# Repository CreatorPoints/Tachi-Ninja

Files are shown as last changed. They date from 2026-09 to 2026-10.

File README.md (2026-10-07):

# Tachi Ninja V2
A 60% Silent Linear mechanical keyboard that has per key RGB lighting and a display for pure asthetics! Made so that I can advance more in this fun cad pathway! [Now Hot-Swappable!]

---

## What was fun to make and what wasnt:
Well, it was overall a great project, I liked the most is the designing the pcb and making the case of this keyboard. But the ABSOLUTE brutal part was manually tracing all 424 pads :skull:

---

## Why did I make this?
I made it because I wanted a actually good keyboard, so instead of buying from online I decided to make my own. Advantages are I get to control how it would be and ofcource the flex :cool:

---

## Whats this "V2" Thingy?
So, when this project was submitted for forge, the reviewer returned the project for multiple reasons, one of it being incomplete PCBA, so, I improvised with something much better. The table would be the best:
|V1|V2|
|--|--|
|Permanent MX Switches|Kailh MX Hot Swappable sockets|
|Very crampy keycaps|Follows universal 19.05mm rule for keyboards|
|More compact, less polished|Kinda less compact, more polished|

## Need this? Here!
So, you need this same keyboard? NO PROBLEM! Its open-source!
1) Download this repo [assuming you know how to... just run git clone in your terminal]
2) Order the PCB - Preferebly from [JLCPCB](jlcpcb.com)
3) Gather the rest of the parts. Check [BOM](./BOM.md) 
4) Case files are in /CAD. Its upto you how to print [#Printing-Legion on slack].
5) Once your assembled PCB arrives, hand-solder the hot-swap sockets and OLED into the board (these are excluded from PCBA since they're through-hole/socketed). Press-fit switches into the hot-swap sockets and mount the PCB into the case and snap on keycaps.
6) Flash the firmware, hold both the BOOT and NRST button when turning on, it turns the stm32 to bootloader mode, drop the .h and json files on a STM32CubeProgrammer and Follow the steps there and then you are good to go!
7) Plug in via USB-C, confirm all 61 keys register, RGB lights up per-key, and the OLED display turns on! Yippe!

---

## Components used:
The following stuffs were used... Very hacky :)
- STM32F072C8Tx
- 1N4148 (x61)
- Kailh MX Hot Swappable Sockets (x61)
- SK6812MINI-E (x63)
- Resistors (x3)
- Capacitors (x6)
- Smol Switches (x2) - For boot & NRST purposes
- USB C 2.0 Receptable 16P
- AMS1117-3.3V
- 0.91 Inch I2C OLED Screen
- USBLC6-2SC6

---
## BOM

| Item | Link | Price | Shipping Cost |
| --- | --- | --- | --- |
| Switches (70x) | [HMX Taro Silent Linear](https://stackskb.com/store/hmx-taro-silent-linear-switch-pack-of-10/) | ₹2,625.00 / $27.39 | Free |
| Stabilizers | [Durock V2 Screw-in Stabilizers](https://stackskb.com/store/durock-clear-screw-in-stabilizers-v2/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) | ₹1,595.00 / $16.65 | Free |
| Keycaps | [dagaladoo Shine Through Keycaps](https://www.amazon.in/gp/product/B0DJH6L159/ref=ox_sc_act_title_1?smid=A2BWJVKSWP7TR2) | ₹2,500.00 / $26.12 | $5.00 |
| Hot Swap Sockets (70x) | [Gateron Sockets](https://stackskb.com/store/gateron-hotswap-sockets/) | ₹610.00 / $6.37 | Free |
| Solder Wire | [Lead-free Solder](https://www.amazon.in/SCHOFIC-Solder-Sn99-Ag0-3-Cu0-7-Weight-0-22lb/dp/B078C7SMKY/ref=sr_1_10?sr=8-10) | ₹385.00 / $4.02 | Free |
| PCB & Top Assembly (2 boards) | [JLCPCB](https://jlcpcb.com) | $53.21 | Included |
| Loose SMD Parts (LEDs, Diodes, CC Resistors) | [LCSC](https://www.lcsc.com) | $9.03 *(parts + handling)* | $42.03 |

Subtotal: $189.82  
Estimated Import Customs (20% – 45% on JLCPCB + LCSC):** ~$21.00 – $47.00 (~$36.50 mid)  
Total Estimated Request: ~$226.30

### For the full itemized breakdown, footprints, and part numbers, check:
[BOM.md](BOM.md)

---

## Images!
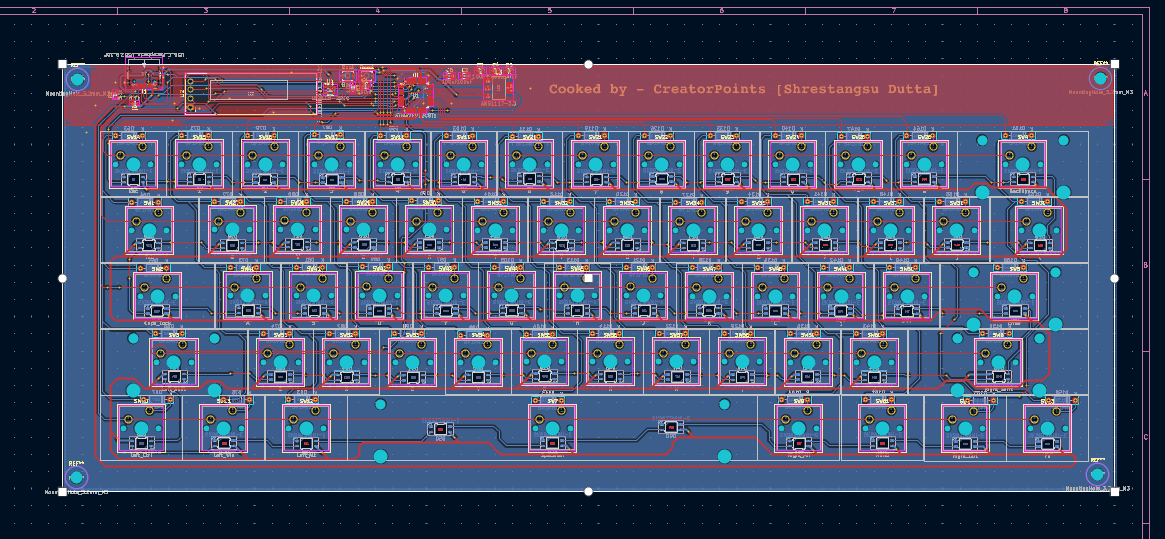
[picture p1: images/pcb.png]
A highly detailed PCB

### Wait, its V1
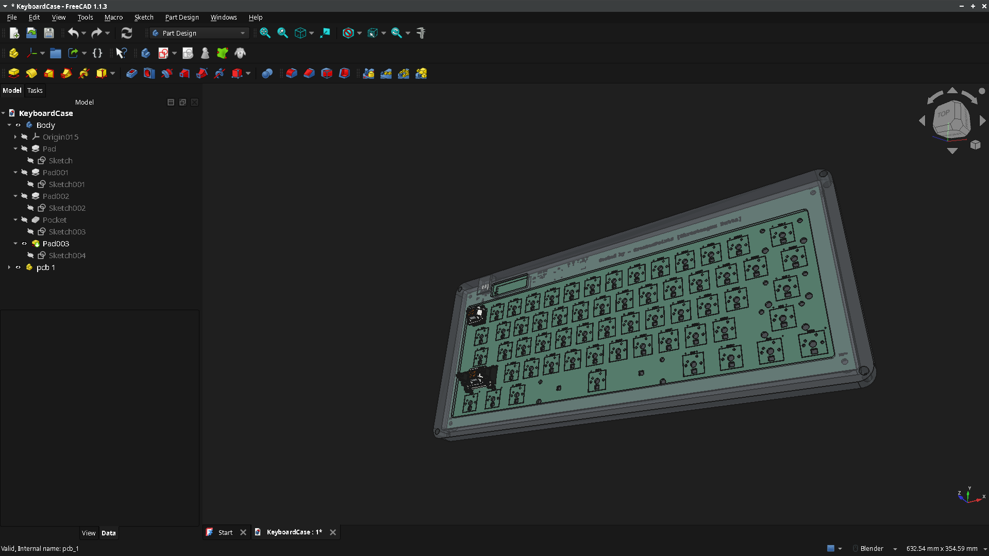
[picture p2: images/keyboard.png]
What a good case!

### From here V2 Development begins
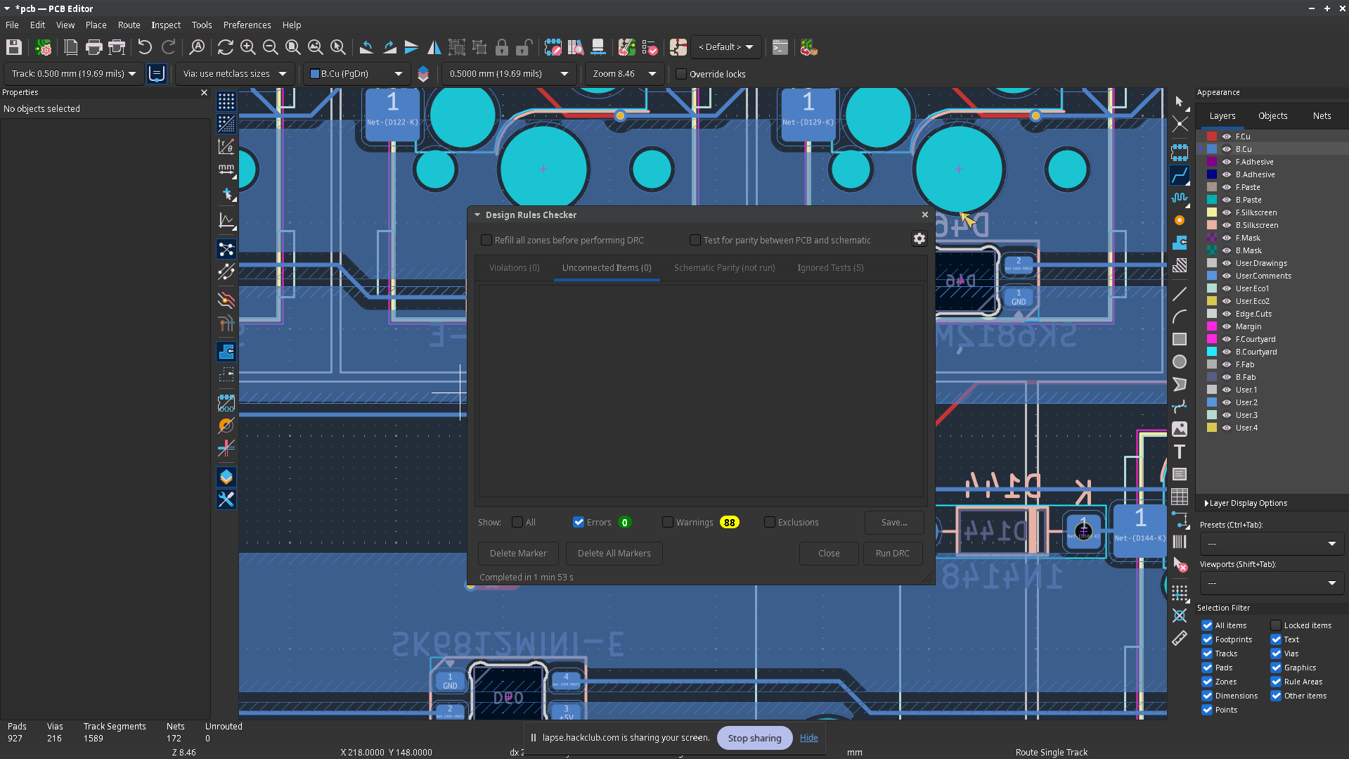
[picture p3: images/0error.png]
No Violations!

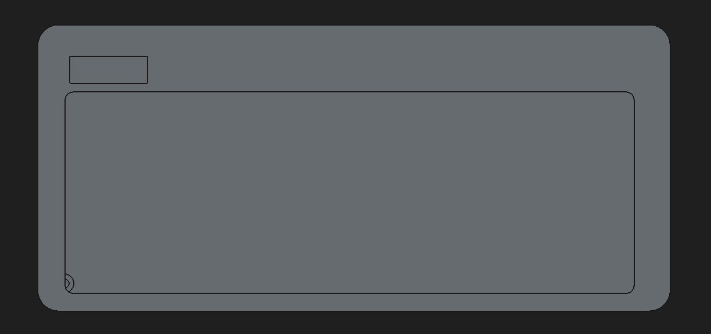
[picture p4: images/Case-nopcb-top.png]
a render

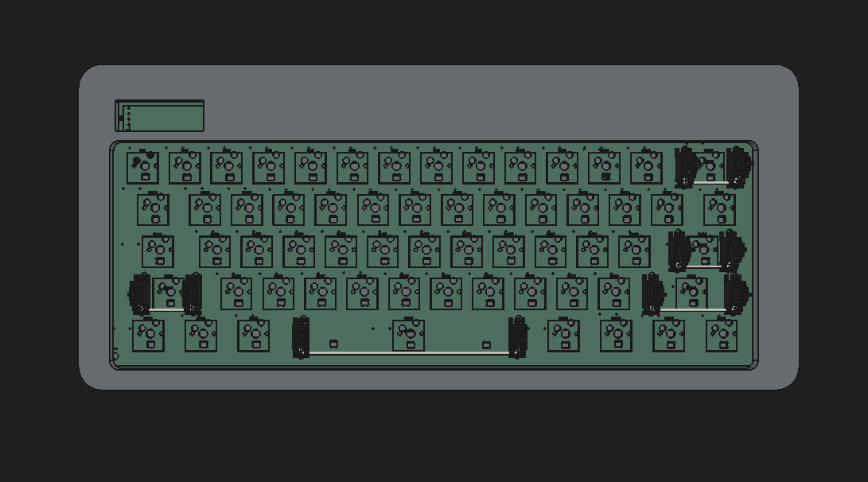
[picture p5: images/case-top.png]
another render

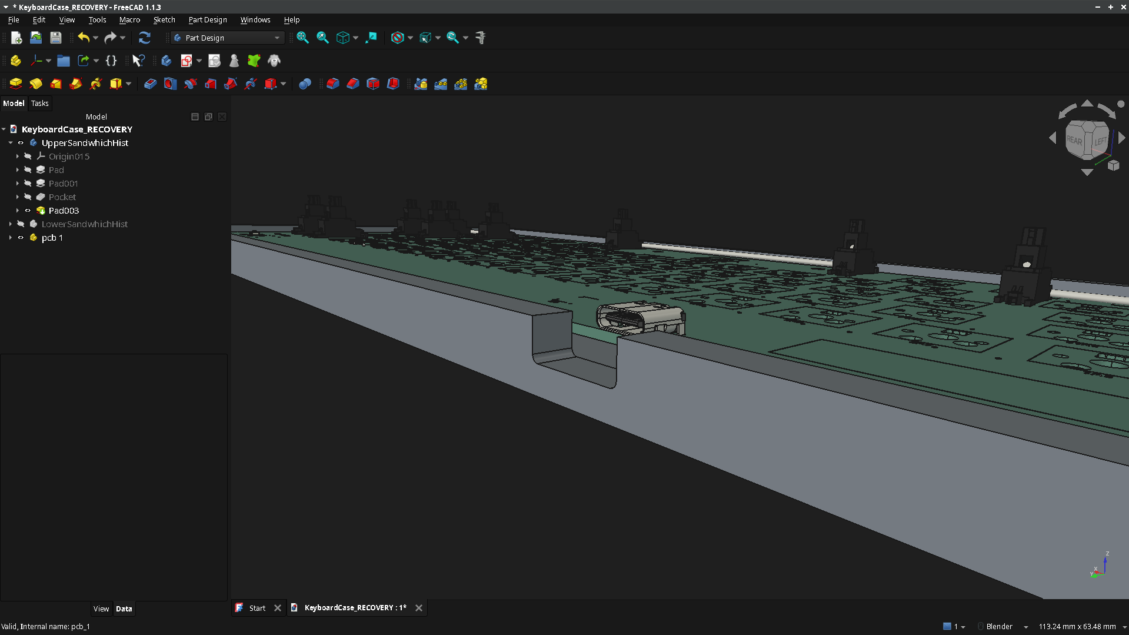
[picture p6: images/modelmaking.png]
i dont know

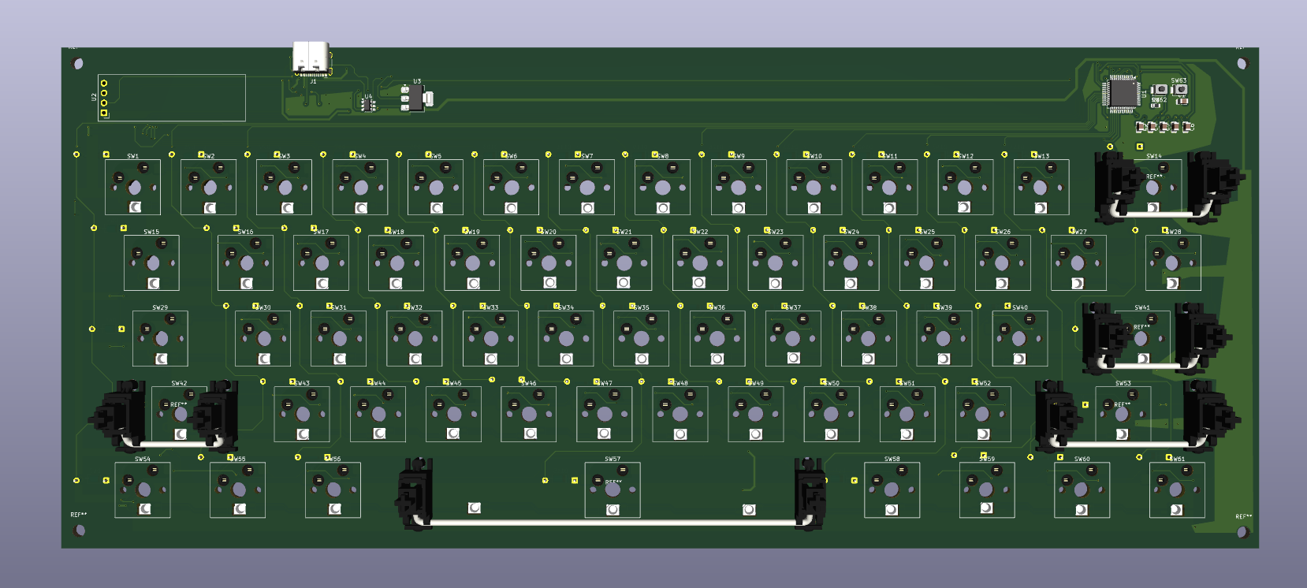
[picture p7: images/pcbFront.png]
pcb!


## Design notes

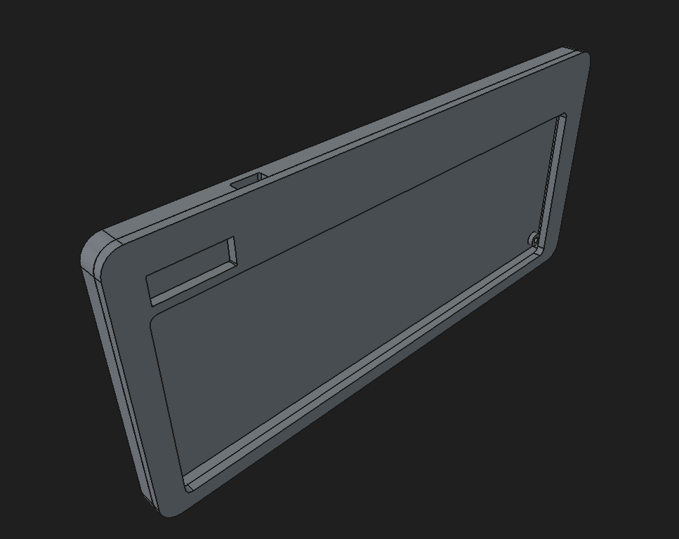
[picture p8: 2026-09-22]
images/case-nopcb-angled.png

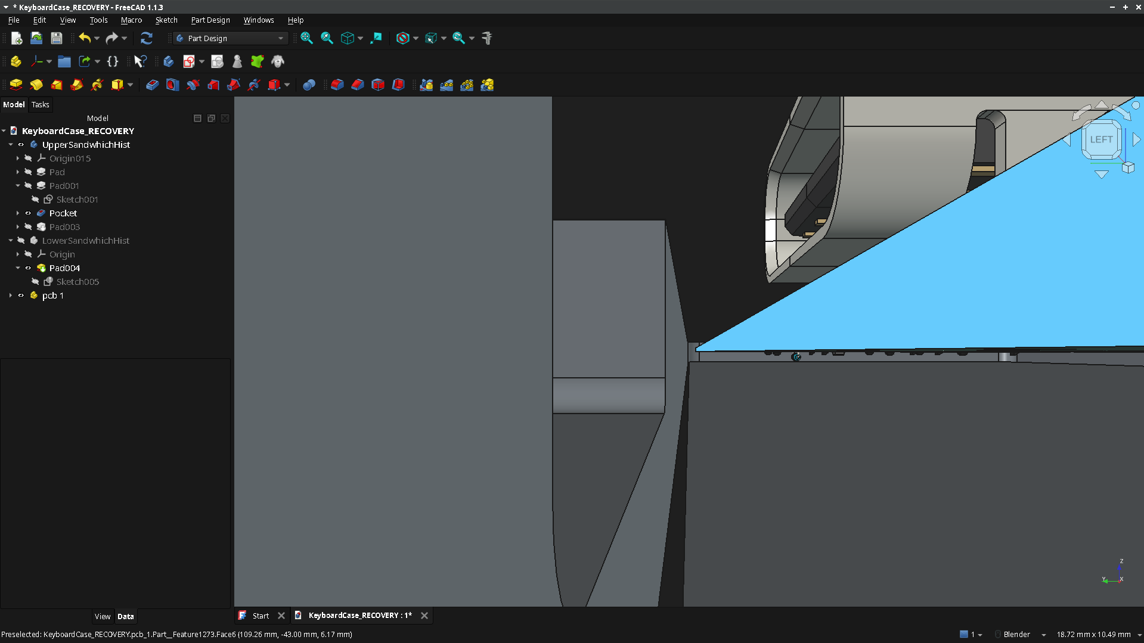
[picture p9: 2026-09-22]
images/checkmodel.png

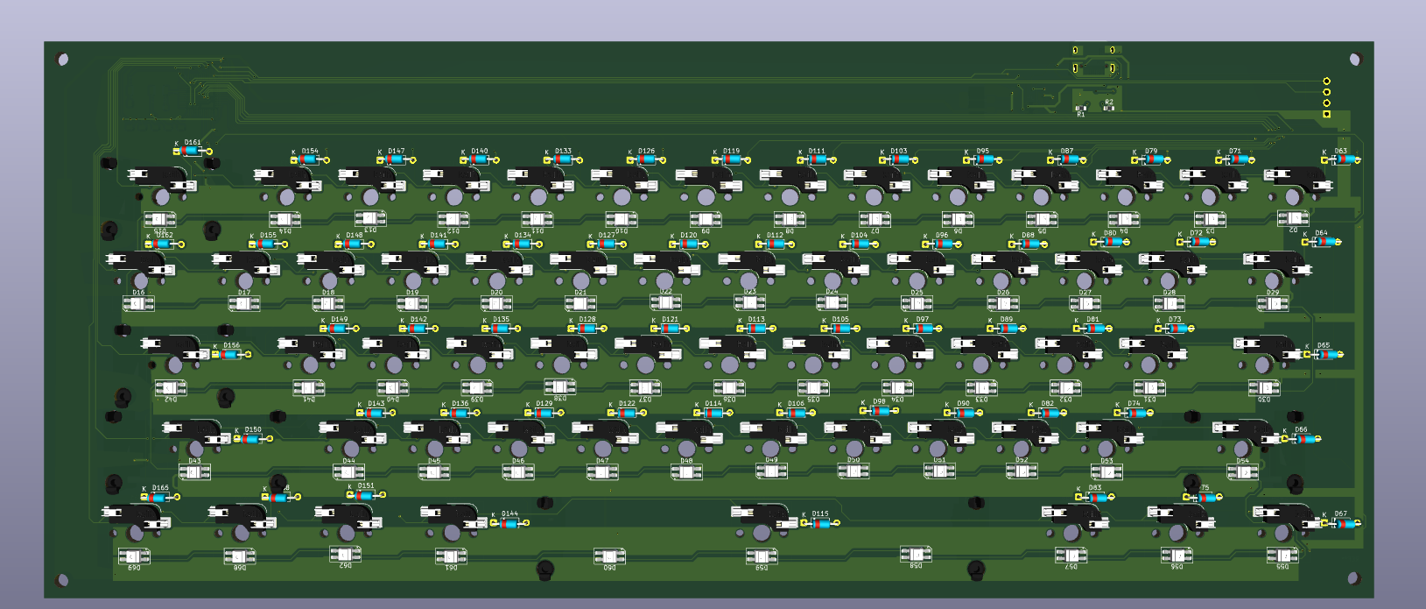
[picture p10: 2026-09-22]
images/pcbBack.png

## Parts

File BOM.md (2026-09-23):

# Bill of Materials
So, first thing is my JLCPCB cart screenshot, here:

### LCSC
| Index | LCSC# | MPN | Manufacturer | Package | Customer # | Description | RoHS | Quantity | MOQ | Multiple | Unit Price($) | Extended Price($) | Product Link |
| :---: | :---: | :---: | :---: | :---: | :---: | :--- | :---: | :---: | :---: | :---: | :---: | :---: | :--- |
| 1 | C5149201 | SK6812MINI-E | OPSCO Optoelectronics | SMD | | SMD LED Addressable, Specialty RoHS | yes | 75 | 5 | 5 | 0.065 | 4.88 | [Link](https://www.lcsc.com/product-detail/C5149201.html) |
| 2 | C402212 | 1N4148 | LGE | DO-35 | | Diode 75V 150mA Through Hole DO-35 | yes | 100 | 50 | 50 | 0.010 | 1.00 | [Link](https://www.lcsc.com/product-detail/C402212.html) |
| 3 | C23186 | 0603WAF5101T5E | UNI-ROYAL | 0603 | | 5.1kΩ ±1% 100mW 0603 Thick Film Resistor | yes | 100 | 100 | 100 | 0.0015 | 0.15 | [Link](https://www.lcsc.com/product-detail/C23186.html) |

YAY! JLCPCB after major removals now cost: $53.21!
and also LCSC: $45.25

Now comes the main costs:
|Sl. no.|Name|Item Link|Price|Shipping|Total|
|---|----|---|-----|---|-----|
|1|dagaladoo Shine Through keycaps Set|[Amazon](https://www.amazon.in/gp/product/B0DJH6L159/ref=ox_sc_act_title_1?smid=A2BWJVKSWP7TR2)|₹2,500 / $26.12|$5|$31.12|
|2|HMX Taro Silent Linear Switch|[StacksKB](https://stackskb.com/store/hmx-taro-silent-linear-switch-pack-of-10/)|₹2,625.00 / $27.39|Free|$27.39|
|3|Stabilizers|[StacksKB](https://stackskb.com/store/durock-clear-screw-in-stabilizers-v2/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)|₹1,595.00 / $16.65|Free|$16.65|
|4|Solder iron|[Amazon](https://www.amazon.in/SCHOFIC-Solder-Sn99-Ag0-3-Cu0-7-Weight-0-22lb/dp/B078C7SMKY/ref=sr_1_10?sr=8-10)|₹385 / $4.02|Free|$10 [as more are needed for more components and i dont own one yet]|
|5|Hot Swap Sockets|[StacksKB](https://stackskb.com/store/gateron-hotswap-sockets/)|₹610 / $6.37|Free|$6.37|

### Final Budget Summary

* **Base Build Total:** **$195.80** (~₹18,740)
* **Customs Buffer Range:** **$20.85 – $46.92** (~₹1,995 – ₹4,490)
* **Final Full Price (with Expected Duties):** **$216.65 – $242.72**  
  *(Recommended Grant Request with mid-range buffer: **$232.29** / ~₹22,230)*

[Used ai for only summary cuz i didnt knew much about customs]

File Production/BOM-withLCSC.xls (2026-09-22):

JLCPCB BOM Tool - BOM Matching
BOM name：bom-JLCPCB Assembly Order.xlsx |  |  | Download Time：2026-09-23 04:56:11 |  |  |  | * Our matching results are updated in real-time, but stock and prices may change. If it's been over 24 hours, please re-match before placing your order.
PCB Assembled Qty：5 |  |  | Est. Total Price：298.9473
Your BOM |  |  |  | Matched Parts |  |  |  |  |  |  | Order Information
Designator | Comment | Footprint | JLCPCB Part # | Matches | Part # | Manufacturer | Footprint | Description | Category | Warning | JLCPCB Part # | Product link | Lib Type | Qty | Source | Total Price ($)
C1,C2,C3,C4,C5,C6 | 100nF | 0805 |  | Select by System | CC0805KRX7R9BB104 | YAGEO | 0805 | 100nF 50V X7R ±10% 0805 Multilayer Ceramic Capacitors MLCC - SMD/SMT ROHS | Multilayer Ceramic Capacitors MLCC - SMD/SMT |  | C49678 | https://jlcpcb.com/partdetail/YAGEO-CC0805KRX7R9BB104/C49678 | Basic | 22 | 22 JLCPCB | 0.4246
D10,D11,D12,D13,D14,D15,D16,D17,D18,D19,D2,D20,D21,D22,D23,D24,D25,D26,D27,D28,D29,D3,D30,D31,D32,D33,D34,D35,D36,D37,D38,D39,D4,D40,D41,D42,D43,D44,D45,D46,D47,D48,D49,D5,D50,D51,D52,D53,D54,D55,D56,D57,D58,D59,D6,D60,D61,D62,D68,D69,D7,D8,D9 | SK6812MINI-E | LED_SK6812MINI-E_3.2x2.8mm_P1.5mm_ReverseMount |  | Select by System | SK6812MINI-E | OPSCO Optoelectronics | SMD | -40℃~+85℃ 0.6mA 1.78mm 120mcd~240mcd 120° 160mcd~320mcd 1kHz 2.8mm 2000V 3.2mm 3.7V~5.5V 460nm~470nm 515nm~525nm 620nm~625nm 800Kbit/s 815mcd~1275mcd Semi-transparent lens SMD RGB LEDs(Built-in IC) ROHS | RGB LEDs(Built-In IC) |  | C5149201 | https://jlcpcb.com/partdetail/OPSCOOptoelectronics-SK6812MINIE/C5149201 | Extended | 128 | 128 JLCPCB | 8.256
D103,D104,D105,D106,D111,D112,D113,D114,D115,D119,D120,D121,D122,D126,D127,D128,D129,D133,D134,D135,D136,D140,D141,D142,D143,D144,D147,D148,D149,D150,D151,D154,D155,D156,D158,D161,D162,D165,D63,D64,D65,D66,D67,D71,D72,D73,D74,D75,D79,D80,D81,D82,D83,D87,D88,D89,D90,D95,D96,D97,D98 | 1N4148 | D_DO-35_SOD27_P7.62mm_Horizontal |  | Select by System | 1N4148 | LGE | DO-35 | 1 Independent 150mA 1V@10mA 2A 4ns 500mW 5uA@75V 75V DO-35 Switching Diodes ROHS | Switching Diodes |  | C402212 | https://jlcpcb.com/partdetail/LGE-1N4148/C402212 | Extended | 127 | 127 JLCPCB | 1.2573
J1 | USB_C_Receptacle_USB2.0_16P | USB_C_Receptacle_HCTL_HC-TYPE-C-16P-01A |  | Select by Customer | USB4105-GF-A | Global Connector Technology | SMD | -40℃~+85℃ 1 12P 48V 5A Black Female Surface Mount, Right Angle Type-C USB 2.0 SMD USB Connectors ROHS | USB Connectors |  | C3020560 | https://jlcpcb.com/partdetail/3542626-USB4105_GFA/C3020560 | Extended | 2 | 2 JLCPCB | 2.5984
R1,R2 | 5.1k | 0603 |  | Unconfirmed | 0603WAF5101T5E | UNI-ROYAL(Uniroyal Elec) | 0603 | -55℃~+155℃ 100mW 5.1kΩ 75V Thick Film Resistor ±1% ±100ppm/℃ 0603 Chip Resistor - Surface Mount ROHS | Chip Resistor - Surface Mount | 1.The comment (0603WAF5101T5E) of this part does not match the one (5.1k) provided in your BOM. Please confirm; | C23186 | https://jlcpcb.com/partdetail/23913-0603WAF5101T5E/C23186 | Basic | 20 | 20 JLCPCB | 0.036
R3 | 10k | 0603 |  | Unconfirmed | 0603WAF1002T5E | UNI-ROYAL(Uniroyal Elec) | 0603 | -55℃~+155℃ 100mW 10kΩ 75V Thick Film Resistor ±1% ±100ppm/℃ 0603 Chip Resistor - Surface Mount ROHS | Chip Resistor - Surface Mount | 1.The comment (0603WAF1002T5E) of this part does not match the one (10k) provided in your BOM. Please confirm; | C25804 | https://jlcpcb.com/partdetail/26547-0603WAF1002T5E/C25804 | Basic | 20 | 20 JLCPCB | 0.036
SW1 | ESC | SW_Hotswap_Kailh_MX_1.00u |  | Select by Customer | CPG151101S11-16 | HanElectricity | SMD,14.5x5.9mm | 12V 2 3000gf 5,000 cycles SMD,14.5x5.9mm Mechanical Keyboard Shaft ROHS | Mechanical Keyboard Shaft | 1.Multiple lines in the BOM have been matched to the same part. Please check if the matching is correct. ; | C41430893 | https://jlcpcb.com/partdetail/HanElectricity-CPG151101S1116/C41430893 | Extended | 122 | 122 JLCPCB | 4.4774
SW2 | 1 | SW_Hotswap_Kailh_MX_1.00u |  | Select by Customer | CPG151101S11-16 | HanElectricity | SMD,14.5x5.9mm | 12V 2 3000gf 5,000 cycles SMD,14.5x5.9mm Mechanical Keyboard Shaft ROHS | Mechanical Keyboard Shaft | 1.The comment (CPG151101S11-16) of this part does not match the one (1) provided in your BOM. Please confirm; 2.Multiple lines in the BOM have been matched to the same part. Please check if the matching is correct. ; | C41430893 | https://jlcpcb.com/partdetail/HanElectricity-CPG151101S1116/C41430893 | Extended | 122 | 122 JLCPCB | 4.4774
SW3 | 2 | SW_Hotswap_Kailh_MX_1.00u |  | Select by Customer | CPG151101S11-16 | HanElectricity | SMD,14.5x5.9mm | 12V 2 3000gf 5,000 cycles SMD,14.5x5.9mm Mechanical Keyboard Shaft ROHS | Mechanical Keyboard Shaft | 1.Multiple lines in the BOM have been matched to the same part. Please check if the matching is correct. ; | C41430893 | https://jlcpcb.com/partdetail/HanElectricity-CPG151101S1116/C41430893 | Extended | 122 | 122 JLCPCB | 4.4774
SW4 | 3 | SW_Hotswap_Kailh_MX_1.00u |  | Select by Customer | CPG151101S11-16 | HanElectricity | SMD,14.5x5.9mm | 12V 2 3000gf 5,000 cycles SMD,14.5x5.9mm Mechanical Keyboard Shaft ROHS | Mechanical Keyboard Shaft | 1.The comment (CPG151101S11-16) of this part does not match the one (3) provided in your BOM. Please confirm; 2.Multiple lines in the BOM have been matched to the same part. Please check if the matching is correct. ; | C41430893 | https://jlcpcb.com/partdetail/HanElectricity-CPG151101S1116/C41430893 | Extended | 122 | 122 JLCPCB | 4.4774
SW5 | 4 | SW_Hotswap_Kailh_MX_1.00u |  | Select by Customer | CPG151101S11-16 | HanElectricity | SMD,14.5x5.9mm | 12V 2 3000gf 5,000 cycles SMD,14.5x5.9mm Mechanical Keyboard Shaft ROHS | Mechanical Keyboard Shaft | 1.The comment (CPG151101S11-16) of this part does not match the one (4) provided in your BOM. Please confirm; 2.Multiple lines in the BOM have been matched to the same part. Please check if the matching is correct. ; | C41430893 | https://jlcpcb.com/partdetail/HanElectricity-CPG151101S1116/C41430893 | Extended | 122 | 122 JLCPCB | 4.4774
SW6 | 5 | SW_Hotswap_Kailh_MX_1.00u |  | Select by Customer | CPG151101S11-16 | HanElectricity | SMD,14.5x5.9mm | 12V 2 3000gf 5,000 cycles SMD,14.5x5.9mm Mechanical Keyboard Shaft ROHS | Mechanical Keyboard Shaft | 1.The comment (CPG151101S11-16) of this part does not match the one (5) provided in your BOM. Please confirm; 2.Multiple lines in the BOM have been matched to the same part. Please check if the matching is correct. ; | C41430893 | https://jlcpcb.com/partdetail/HanElectricity-CPG151101S1116/C41430893 | Extended | 122 | 122 JLCPCB | 4.4774
SW7 | 6 | SW_Hotswap_Kailh_MX_1.00u |  | Select by Customer | CPG151101S11-16 | HanElectricity | SMD,14.5x5.9mm | 12V 2 3000gf 5,000 cycles SMD,14.5x5.9mm Mechanical Keyboard Shaft ROHS | Mechanical Keyboard Shaft | 1.The comment (CPG151101S11-16) of this part does not match the one (6) provided in your BOM. Please confirm; 2.Multiple lines in the BOM have been matched to the same part. Please check if the matching is correct. ; | C41430893 | https://jlcpcb.com/partdetail/HanElectricity-CPG151101S1116/C41430893 | Extended | 122 | 122 JLCPCB | 4.4774
SW8 | 7 | SW_Hotswap_Kailh_MX_1.00u |  | Select by Customer | CPG151101S11-16 | HanElectricity | SMD,14.5x5.9mm | 12V 2 3000gf 5,000 cycles SMD,14.5x5.9mm Mechanical Keyboard Shaft ROHS | Mechanical Keyboard Shaft | 1.The comment (CPG151101S11-16) of this part does not match the one (7) provided in your BOM. Please confirm; 2.Multiple lines in the BOM have been matched to the same part. Please check if the matching is correct. ; | C41430893 | https://jlcpcb.com/partdetail/HanElectricity-CPG151101S1116/C41430893 | Extended | 122 | 122 JLCPCB | 4.4774
SW9 | 8 | SW_Hotswap_Kailh_MX_1.00u |  | Select by Customer | CPG151101S11-16 | HanElectricity | SMD,14.5x5.9mm | 12V 2 3000gf 5,000 cycles SMD,14.5x5.9mm Mechanical Keyboard Shaft ROHS | Mechanical Keyboard Shaft | 1.The comment (CPG151101S11-16) of this part does not match the one (8) provided in your BOM. Please confirm; 2.Multiple lines in the BOM have been matched to the same part. Please check if the matching is correct. ; | C41430893 | https://jlcpcb.com/partdetail/HanElectricity-CPG151101S1116/C41430893 | Extended | 122 | 122 JLCPCB | 4.4774
SW10 | 9 | SW_Hotswap_Kailh_MX_1.00u |  | Select by Customer | CPG151101S11-16 | HanElectricity | SMD,14.5x5.9mm | 12V 2 3000gf 5,000 cycles SMD,14.5x5.9mm Mechanical Keyboard Shaft ROHS | Mechanical Keyboard Shaft | 1.The comment (CPG151101S11-16) of this part does not match the one (9) provided in your BOM. Please confirm; 2.Multiple lines in the BOM have been matched to the same part. Please check if the matching is correct. ; | C41430893 | https://jlcpcb.com/partdetail/HanElectricity-CPG151101S1116/C41430893 | Extended | 122 | 122 JLCPCB | 4.4774
SW11 | 0 | SW_Hotswap_Kailh_MX_1.00u |  | Select by Customer | CPG151101S11-16 | HanElectricity | SMD,14.5x5.9mm | 12V 2 3000gf 5,000 cycles SMD,14.5x5.9mm Mechanical Keyboard Shaft ROHS | Mechanical Keyboard Shaft | 1.The comment (CPG151101S11-16) of this part does not match the one (0) provided in your BOM. Please confirm; 2.Multiple lines in the BOM have been matched to the same part. Please check if the matching is correct. ; | C41430893 | https://jlcpcb.com/partdetail/HanElectricity-CPG151101S1116/C41430893 | Extended | 122 | 122 JLCPCB | 4.4774
SW12 | - | SW_Hotswap_Kailh_MX_1.00u |  | Select by Customer | CPG151101S11-16 | HanElectricity | SMD,14.5x5.9mm | 12V 2 3000gf 5,000 cycles SMD,14.5x5.9mm Mechanical Keyboard Shaft ROHS | Mechanical Keyboard Shaft | 1.Multiple lines in the BOM have been matched to the same part. Please check if the matching is correct. ; | C41430893 | https://jlcpcb.com/partdetail/HanElectricity-CPG151101S1116/C41430893 | Extended | 122 | 122 JLCPCB | 4.4774
SW13 | = | SW_Hotswap_Kailh_MX_1.00u |  | Select by Customer | CPG151101S11-16 | HanElectricity | SMD,14.5x5.9mm | 12V 2 3000gf 5,000 cycles SMD,14.5x5.9mm Mechanical Keyboard Shaft ROHS | Mechanical Keyboard Shaft | 1.Multiple lines in the BOM have been matched to the same part. Please check if the matching is correct. ; | C41430893 | https://jlcpcb.com/partdetail/HanElectricity-CPG151101S1116/C41430893 | Extended | 122 | 122 JLCPCB | 4.4774
SW14 | BACKSPACE | SW_Hotswap_Kailh_MX_2.00u |  | Select by Customer | CPG151101S11-16 | HanElectricity | SMD,14.5x5.9mm | 12V 2 3000gf 5,000 cycles SMD,14.5x5.9mm Mechanical Keyboard Shaft ROHS | Mechanical Keyboard Shaft | 1.Multiple lines in the BOM have been matched to the same part. Please check if the matching is correct. ; | C41430893 | https://jlcpcb.com/partdetail/HanElectricity-CPG151101S1116/C41430893 | Extended | 122 | 122 JLCPCB | 4.4774
SW15 | TAB | SW_Hotswap_Kailh_MX_1.50u |  | Select by Customer | CPG151101S11-16 | HanElectricity | SMD,14.5x5.9mm | 12V 2 3000gf 5,000 cycles SMD,14.5x5.9mm Mechanical Keyboard Shaft ROHS | Mechanical Keyboard Shaft | 1.Multiple lines in the BOM have been matched to the same part. Please check if the matching is correct. ; | C41430893 | https://jlcpcb.com/partdetail/HanElectricity-CPG151101S1116/C41430893 | Extended | 122 | 122 JLCPCB | 4.4774
SW16 | Q | SW_Hotswap_Kailh_MX_1.00u |  | Select by Customer | CPG151101S11-16 | HanElectricity | SMD,14.5x5.9mm | 12V 2 3000gf 5,000 cycles SMD,14.5x5.9mm Mechanical Keyboard Shaft ROHS | Mechanical Keyboard Shaft | 1.Multiple lines in the BOM have been matched to the same part. Please check if the matching is correct. ; | C41430893 | https://jlcpcb.com/partdetail/HanElectricity-CPG151101S1116/C41430893 | Extended | 122 | 122 JLCPCB | 4.4774
SW17 | W | SW_Hotswap_Kailh_MX_1.00u |  | Unconfirmed | CPG151101S11-16 | HanElectricity | SMD,14.5x5.9mm | 12V 2 3000gf 5,000 cycles SMD,14.5x5.9mm Mechanical Keyboard Shaft ROHS | Mechanical Keyboard Shaft | 1.Multiple lines in the BOM have been matched to the same part. Please check if the matching is correct. ; | C41430893 | https://jlcpcb.com/partdetail/HanElectricity-CPG151101S1116/C41430893 | Extended | 122 | 122 JLCPCB | 4.4774
SW18 | E | SW_Hotswap_Kailh_MX_1.00u |  | Select by Customer | CPG151101S11-16 | HanElectricity | SMD,14.5x5.9mm | 12V 2 3000gf 5,000 cycles SMD,14.5x5.9mm Mechanical Keyboard Shaft ROHS | Mechanical Keyboard Shaft | 1.Multiple lines in the BOM have been matched to the same part. Please check if the matching is correct. ; | C41430893 | https://jlcpcb.com/partdetail/HanElectricity-CPG151101S1116/C41430893 | Extended | 122 | 122 JLCPCB | 4.4774
SW19 | R | SW_Hotswap_Kailh_MX_1.00u |  | Select by Customer | CPG151101S11-16 | HanElectricity | SMD,14.5x5.9mm | 12V 2 3000gf 5,000 cycles SMD,14.5x5.9mm Mechanical Keyboard Shaft ROHS | Mechanical Keyboard Shaft | 1.Multiple lines in the BOM have been matched to the same part. Please check if the matching is correct. ; | C41430893 | https://jlcpcb.com/partdetail/HanElectricity-CPG151101S1116/C41430893 | Extended | 122 | 122 JLCPCB | 4.4774
SW20 | T | SW_Hotswap_Kailh_MX_1.00u |  | Select by Customer | CPG151101S11-16 | HanElectricity | SMD,14.5x5.9mm | 12V 2 3000gf 5,000 cycles SMD,14.5x5.9mm Mechanical Keyboard Shaft ROHS | Mechanical Keyboard Shaft | 1.Multiple lines in the BOM have been matched to the same part. Please check if the matching is correct. ; | C41430893 | https://jlcpcb.com/partdetail/HanElectricity-CPG151101S1116/C41430893 | Extended | 122 | 122 JLCPCB | 4.4774
SW21 | Y | SW_Hotswap_Kailh_MX_1.00u |  | Select by Customer | CPG151101S11-16 | HanElectricity | SMD,14.5x5.9mm | 12V 2 3000gf 5,000 cycles SMD,14.5x5.9mm Mechanical Keyboard Shaft ROHS | Mechanical Keyboard Shaft | 1.Multiple lines in the BOM have been matched to the same part. Please check if the matching is correct. ; | C41430893 | https://jlcpcb.com/partdetail/HanElectricity-CPG151101S1116/C41430893 | Extended | 122 | 122 JLCPCB | 4.4774
SW22 | U | SW_Hotswap_Kailh_MX_1.00u |  | Select by Customer | CPG151101S11-16 | HanElectricity | SMD,14.5x5.9mm | 12V 2 3000gf 5,000 cycles SMD,14.5x5.9mm Mechanical Keyboard Shaft ROHS | Mechanical Keyboard Shaft | 1.Multiple lines in the BOM have been matched to the same part. Please check if the matching is correct. ; | C41430893 | https://jlcpcb.com/partdetail/HanElectricity-CPG151101S1116/C41430893 | Extended | 122 | 122 JLCPCB | 4.4774
SW23 | I | SW_Hotswap_Kailh_MX_1.00u |  | Select by Customer | CPG151101S11-16 | HanElectricity | SMD,14.5x5.9mm | 12V 2 3000gf 5,000 cycles SMD,14.5x5.9mm Mechanical Keyboard Shaft ROHS | Mechanical Keyboard Shaft | 1.Multiple lines in the BOM have been matched to the same part. Please check if the matching is correct. ; | C41430893 | https://jlcpcb.com/partdetail/HanElectricity-CPG151101S1116/C41430893 | Extended | 122 | 122 JLCPCB | 4.4774
SW24 | O | SW_Hotswap_Kailh_MX_1.00u |  | Select by Customer | CPG151101S11-16 | HanElectricity | SMD,14.5x5.9mm | 12V 2 3000gf 5,000 cycles SMD,14.5x5.9mm Mechanical Keyboard Shaft ROHS | Mechanical Keyboard Shaft | 1.Multiple lines in the BOM have been matched to the same part. Please check if the matching is correct. ; | C41430893 | https://jlcpcb.com/partdetail/HanElectricity-CPG151101S1116/C41430893 | Extended | 122 | 122 JLCPCB | 4.4774
SW25 | P | SW_Hotswap_Kailh_MX_1.00u |  | Select by Customer | CPG151101S11-16 | HanElectricity | SMD,14.5x5.9mm | 12V 2 3000gf 5,000 cycles SMD,14.5x5.9mm Mechanical Keyboard Shaft ROHS | Mechanical Keyboard Shaft | 1.Multiple lines in the BOM have been matched to the same part. Please check if the matching is correct. ; | C41430893 | https://jlcpcb.com/partdetail/HanElectricity-CPG151101S1116/C41430893 | Extended | 122 | 122 JLCPCB | 4.4774
SW26 | [ | SW_Hotswap_Kailh_MX_1.00u |  | Select by Customer | CPG151101S11-16 | HanElectricity | SMD,14.5x5.9mm | 12V 2 3000gf 5,000 cycles SMD,14.5x5.9mm Mechanical Keyboard Shaft ROHS | Mechanical Keyboard Shaft | 1.Multiple lines in the BOM have been matched to the same part. Please check if the matching is correct. ; | C41430893 | https://jlcpcb.com/partdetail/HanElectricity-CPG151101S1116/C41430893 | Extended | 122 | 122 JLCPCB | 4.4774
SW27 | ] | SW_Hotswap_Kailh_MX_1.00u |  | Select by Customer | CPG151101S11-16 | HanElectricity | SMD,14.5x5.9mm | 12V 2 3000gf 5,000 cycles SMD,14.5x5.9mm Mechanical Keyboard Shaft ROHS | Mechanical Keyboard Shaft | 1.Multiple lines in the BOM have been matched to the same part. Please check if the matching is correct. ; | C41430893 | https://jlcpcb.com/partdetail/HanElectricity-CPG151101S1116/C41430893 | Extended | 122 | 122 JLCPCB | 4.4774
SW28 | \ | SW_Hotswap_Kailh_MX_1.50u |  | Select by Customer | CPG151101S11-16 | HanElectricity | SMD,14.5x5.9mm | 12V 2 3000gf 5,000 cycles SMD,14.5x5.9mm Mechanical Keyboard Shaft ROHS | Mechanical Keyboard Shaft | 1.Multiple lines in the BOM have been matched to the same part. Please check if the matching is correct. ; | C41430893 | https://jlcpcb.com/partdetail/HanElectricity-CPG151101S1116/C41430893 | Extended | 122 | 122 JLCPCB | 4.4774
SW29 | CAPSLOCK | SW_Hotswap_Kailh_MX_1.75u |  | Select by Customer | CPG151101S11-16 | HanElectricity | SMD,14.5x5.9mm | 12V 2 3000gf 5,000 cycles SMD,14.5x5.9mm Mechanical Keyboard Shaft ROHS | Mechanical Keyboard Shaft | 1.Multiple lines in the BOM have been matched to the same part. Please check if the matching is correct. ; | C41430893 | https://jlcpcb.com/partdetail/HanElectricity-CPG151101S1116/C41430893 | Extended | 122 | 122 JLCPCB | 4.4774
SW30 | A | SW_Hotswap_Kailh_MX_1.00u |  | Select by Customer | CPG151101S11-16 | HanElectricity | SMD,14.5x5.9mm | 12V 2 3000gf 5,000 cycles SMD,14.5x5.9mm Mechanical Keyboard Shaft ROHS | Mechanical Keyboard Shaft | 1.Multiple lines in the BOM have been matched to the same part. Please check if the matching is correct. ; | C41430893 | https://jlcpcb.com/partdetail/HanElectricity-CPG151101S1116/C41430893 | Extended | 122 | 122 JLCPCB | 4.4774
SW31 | S | SW_Hotswap_Kailh_MX_1.00u |  | Select by Customer | CPG151101S11-16 | HanElectricity | SMD,14.5x5.9mm | 12V 2 3000gf 5,000 cycles SMD,14.5x5.9mm Mechanical Keyboard Shaft ROHS | Mechanical Keyboard Shaft | 1.Multiple lines in the BOM have been matched to the same part. Please check if the matching is correct. ; | C41430893 | https://jlcpcb.com/partdetail/HanElectricity-CPG151101S1116/C41430893 | Extended | 122 | 122 JLCPCB | 4.4774
SW32 | D | SW_Hotswap_Kailh_MX_1.00u |  | Select by Customer | CPG151101S11-16 | HanElectricity | SMD,14.5x5.9mm | 12V 2 3000gf 5,000 cycles SMD,14.5x5.9mm Mechanical Keyboard Shaft ROHS | Mechanical Keyboard Shaft | 1.Multiple lines in the BOM have been matched to the same part. Please check if the matching is correct. ; | C41430893 | https://jlcpcb.com/partdetail/HanElectricity-CPG151101S1116/C41430893 | Extended | 122 | 122 JLCPCB | 4.4774
SW33 | F | SW_Hotswap_Kailh_MX_1.00u |  | Select by Customer | CPG151101S11-16 | HanElectricity | SMD,14.5x5.9mm | 12V 2 3000gf 5,000 cycles SMD,14.5x5.9mm Mechanical Keyboard Shaft ROHS | Mechanical Keyboard Shaft | 1.Multiple lines in the BOM have been matched to the same part. Please check if the matching is correct. ; | C41430893 | https://jlcpcb.com/partdetail/HanElectricity-CPG151101S1116/C41430893 | Extended | 122 | 122 JLCPCB | 4.4774
SW34 | G | SW_Hotswap_Kailh_MX_1.00u |  | Select by Customer | CPG151101S11-16 | HanElectricity | SMD,14.5x5.9mm | 12V 2 3000gf 5,000 cycles SMD,14.5x5.9mm Mechanical Keyboard Shaft ROHS | Mechanical Keyboard Shaft | 1.Multiple lines in the BOM have been matched to the same part. Please check if the matching is correct. ; | C41430893 | https://jlcpcb.com/partdetail/HanElectricity-CPG151101S1116/C41430893 | Extended | 122 | 122 JLCPCB | 4.4774
SW35 | H | SW_Hotswap_Kailh_MX_1.00u |  | Select by Customer | CPG151101S11-16 | HanElectricity | SMD,14.5x5.9mm | 12V 2 3000gf 5,000 cycles SMD,14.5x5.9mm Mechanical Keyboard Shaft ROHS | Mechanical Keyboard Shaft | 1.Multiple lines in the BOM have been matched to the same part. Please check if the matching is correct. ; | C41430893 | https://jlcpcb.com/partdetail/HanElectricity-CPG151101S1116/C41430893 | Extended | 122 | 122 JLCPCB | 4.4774
SW36 | J | SW_Hotswap_Kailh_MX_1.00u |  | Select by Customer | CPG151101S11-16 | HanElectricity | SMD,14.5x5.9mm | 12V 2 3000gf 5,000 cycles SMD,14.5x5.9mm Mechanical Keyboard Shaft ROHS | Mechanical Keyboard Shaft | 1.Multiple lines in the BOM have been matched to the same part. Please check if the matching is correct. ; | C41430893 | https://jlcpcb.com/partdetail/HanElectricity-CPG151101S1116/C41430893 | Extended | 122 | 122 JLCPCB | 4.4774
SW37 | K | SW_Hotswap_Kailh_MX_1.00u |  | Select by Customer | CPG151101S11-16 | HanElectricity | SMD,14.5x5.9mm | 12V 2 3000gf 5,000 cycles SMD,14.5x5.9mm Mechanical Keyboard Shaft ROHS | Mechanical Keyboard Shaft | 1.Multiple lines in the BOM have been matched to the same part. Please check if the matching is correct. ; | C41430893 | https://jlcpcb.com/partdetail/HanElectricity-CPG151101S1116/C41430893 | Extended | 122 | 122 JLCPCB | 4.4774
SW38 | L | SW_Hotswap_Kailh_MX_1.00u |  | Select by Customer | CPG151101S11-16 | HanElectricity | SMD,14.5x5.9mm | 12V 2 3000gf 5,000 cycles SMD,14.5x5.9mm Mechanical Keyboard Shaft ROHS | Mechanical Keyboard Shaft | 1.Multiple lines in the BOM have been matched to the same part. Please check if the matching is correct. ; | C41430893 | https://jlcpcb.com/partdetail/HanElectricity-CPG151101S1116/C41430893 | Extended | 122 | 122 JLCPCB | 4.4774
SW39 | ; | SW_Hotswap_Kailh_MX_1.00u |  | Select by Customer | CPG151101S11-16 | HanElectricity | SMD,14.5x5.9mm | 12V 2 3000gf 5,000 cycles SMD,14.5x5.9mm Mechanical Keyboard Shaft ROHS | Mechanical Keyboard Shaft | 1.Multiple lines in the BOM have been matched to the same part. Please check if the matching is correct. ; | C41430893 | https://jlcpcb.com/partdetail/HanElectricity-CPG151101S1116/C41430893 | Extended | 122 | 122 JLCPCB | 4.4774
SW40 | ' | SW_Hotswap_Kailh_MX_1.00u |  | Select by Customer | CPG151101S11-16 | HanElectricity | SMD,14.5x5.9mm | 12V 2 3000gf 5,000 cycles SMD,14.5x5.9mm Mechanical Keyboard Shaft ROHS | Mechanical Keyboard Shaft | 1.Multiple lines in the BOM have been matched to the same part. Please check if the matching is correct. ; | C41430893 | https://jlcpcb.com/partdetail/HanElectricity-CPG151101S1116/C41430893 | Extended | 122 | 122 JLCPCB | 4.4774
SW41 | ENTER | SW_Hotswap_Kailh_MX_2.25u |  | Select by Customer | CPG151101S11-16 | HanElectricity | SMD,14.5x5.9mm | 12V 2 3000gf 5,000 cycles SMD,14.5x5.9mm Mechanical Keyboard Shaft ROHS | Mechanical Keyboard Shaft | 1.Multiple lines in the BOM have been matched to the same part. Please check if the matching is correct. ; | C41430893 | https://jlcpcb.com/partdetail/HanElectricity-CPG151101S1116/C41430893 | Extended | 122 | 122 JLCPCB | 4.4774
SW42 | LEFTSHIFT | SW_Hotswap_Kailh_MX_2.25u |  | Select by Customer | CPG151101S11-16 | HanElectricity | SMD,14.5x5.9mm | 12V 2 3000gf 5,000 cycles SMD,14.5x5.9mm Mechanical Keyboard Shaft ROHS | Mechanical Keyboard Shaft | 1.Multiple lines in the BOM have been matched to the same part. Please check if the matching is correct. ; | C41430893 | https://jlcpcb.com/partdetail/HanElectricity-CPG151101S1116/C41430893 | Extended | 122 | 122 JLCPCB | 4.4774
SW43 | Z | SW_Hotswap_Kailh_MX_1.00u |  | Select by Customer | CPG151101S11-16 | HanElectricity | SMD,14.5x5.9mm | 12V 2 3000gf 5,000 cycles SMD,14.5x5.9mm Mechanical Keyboard Shaft ROHS | Mechanical Keyboard Shaft | 1.Multiple lines in the BOM have been matched to the same part. Please check if the matching is correct. ; | C41430893 | https://jlcpcb.com/partdetail/HanElectricity-CPG151101S1116/C41430893 | Extended | 122 | 122 JLCPCB | 4.4774
SW44 | X | SW_Hotswap_Kailh_MX_1.00u |  | Select by Customer | CPG151101S11-16 | HanElectricity | SMD,14.5x5.9mm | 12V 2 3000gf 5,000 cycles SMD,14.5x5.9mm Mechanical Keyboard Shaft ROHS | Mechanical Keyboard Shaft | 1.Multiple lines in the BOM have been matched to the same part. Please check if the matching is correct. ; | C41430893 | https://jlcpcb.com/partdetail/HanElectricity-CPG151101S1116/C41430893 | Extended | 122 | 122 JLCPCB | 4.4774
SW45 | C | SW_Hotswap_Kailh_MX_1.00u |  | Select by Customer | CPG151101S11-16 | HanElectricity | SMD,14.5x5.9mm | 12V 2 3000gf 5,000 cycles SMD,14.5x5.9mm Mechanical Keyboard Shaft ROHS | Mechanical Keyboard Shaft | 1.Multiple lines in the BOM have been matched to the same part. Please check if the matching is correct. ; | C41430893 | https://jlcpcb.com/partdetail/HanElectricity-CPG151101S1116/C41430893 | Extended | 122 | 122 JLCPCB | 4.4774
SW46 | V | SW_Hotswap_Kailh_MX_1.00u |  | Select by Customer | CPG151101S11-16 | HanElectricity | SMD,14.5x5.9mm | 12V 2 3000gf 5,000 cycles SMD,14.5x5.9mm Mechanical Keyboard Shaft ROHS | Mechanical Keyboard Shaft | 1.Multiple lines in the BOM have been matched to the same part. Please check if the matching is correct. ; | C41430893 | https://jlcpcb.com/partdetail/HanElectricity-CPG151101S1116/C41430893 | Extended | 122 | 122 JLCPCB | 4.4774
SW47 | B | SW_Hotswap_Kailh_MX_1.00u |  | Select by Customer | CPG151101S11-16 | HanElectricity | SMD,14.5x5.9mm | 12V 2 3000gf 5,000 cycles SMD,14.5x5.9mm Mechanical Keyboard Shaft ROHS | Mechanical Keyboard Shaft | 1.Multiple lines in the BOM have been matched to the same part. Please check if the matching is correct. ; | C41430893 | https://jlcpcb.com/partdetail/HanElectricity-CPG151101S1116/C41430893 | Extended | 122 | 122 JLCPCB | 4.4774
SW48 | N | SW_Hotswap_Kailh_MX_1.00u |  | Select by Customer | CPG151101S11-16 | HanElectricity | SMD,14.5x5.9mm | 12V 2 3000gf 5,000 cycles SMD,14.5x5.9mm Mechanical Keyboard Shaft ROHS | Mechanical Keyboard Shaft | 1.Multiple lines in the BOM have been matched to the same part. Please check if the matching is correct. ; | C41430893 | https://jlcpcb.com/partdetail/HanElectricity-CPG151101S1116/C41430893 | Extended | 122 | 122 JLCPCB | 4.4774
SW49 | M | SW_Hotswap_Kailh_MX_1.00u |  | Select by Customer | CPG151101S11-16 | HanElectricity | SMD,14.5x5.9mm | 12V 2 3000gf 5,000 cycles SMD,14.5x5.9mm Mechanical Keyboard Shaft ROHS | Mechanical Keyboard Shaft | 1.Multiple lines in the BOM have been matched to the same part. Please check if the matching is correct. ; | C41430893 | https://jlcpcb.com/partdetail/HanElectricity-CPG151101S1116/C41430893 | Extended | 122 | 122 JLCPCB | 4.4774
SW50 | , | SW_Hotswap_Kailh_MX_1.00u |  | Select by Customer | CPG151101S11-16 | HanElectricity | SMD,14.5x5.9mm | 12V 2 3000gf 5,000 cycles SMD,14.5x5.9mm Mechanical Keyboard Shaft ROHS | Mechanical Keyboard Shaft | 1.Multiple lines in the BOM have been matched to the same part. Please check if the matching is correct. ; | C41430893 | https://jlcpcb.com/partdetail/HanElectricity-CPG151101S1116/C41430893 | Extended | 122 | 122 JLCPCB | 4.4774
SW51 | . | SW_Hotswap_Kailh_MX_1.00u |  | Select by Customer | CPG151101S11-16 | HanElectricity | SMD,14.5x5.9mm | 12V 2 3000gf 5,000 cycles SMD,14.5x5.9mm Mechanical Keyboard Shaft ROHS | Mechanical Keyboard Shaft | 1.Multiple lines in the BOM have been matched to the same part. Please check if the matching is correct. ; | C41430893 | https://jlcpcb.com/partdetail/HanElectricity-CPG151101S1116/C41430893 | Extended | 122 | 122 JLCPCB | 4.4774
SW52 | / | SW_Hotswap_Kailh_MX_1.00u |  | Select by Customer | CPG151101S11-16 | HanElectricity | SMD,14.5x5.9mm | 12V 2 3000gf 5,000 cycles SMD,14.5x5.9mm Mechanical Keyboard Shaft ROHS | Mechanical Keyboard Shaft | 1.Multiple lines in the BOM have been matched to the same part. Please check if the matching is correct. ; | C41430893 | https://jlcpcb.com/partdetail/HanElectricity-CPG151101S1116/C41430893 | Extended | 122 | 122 JLCPCB | 4.4774
SW53 | RIGHTSHIFT | SW_Hotswap_Kailh_MX_2.75u |  | Select by Customer | CPG151101S11-16 | HanElectricity | SMD,14.5x5.9mm | 12V 2 3000gf 5,000 cycles SMD,14.5x5.9mm Mechanical Keyboard Shaft ROHS | Mechanical Keyboard Shaft | 1.Multiple lines in the BOM have been matched to the same part. Please check if the matching is correct. ; | C41430893 | https://jlcpcb.com/partdetail/HanElectricity-CPG151101S1116/C41430893 | Extended | 122 | 122 JLCPCB | 4.4774
SW54 | LEFTCTRL | SW_Hotswap_Kailh_MX_1.25u |  | Select by Customer | CPG151101S11-16 | HanElectricity | SMD,14.5x5.9mm | 12V 2 3000gf 5,000 cycles SMD,14.5x5.9mm Mechanical Keyboard Shaft ROHS | Mechanical Keyboard Shaft | 1.Multiple lines in the BOM have been matched to the same part. Please check if the matching is correct. ; | C41430893 | https://jlcpcb.com/partdetail/HanElectricity-CPG151101S1116/C41430893 | Extended | 122 | 122 JLCPCB | 4.4774
SW55 | LEFTWIN | SW_Hotswap_Kailh_MX_1.25u |  | Select by Customer | CPG151101S11-16 | HanElectricity | SMD,14.5x5.9mm | 12V 2 3000gf 5,000 cycles SMD,14.5x5.9mm Mechanical Keyboard Shaft ROHS | Mechanical Keyboard Shaft | 1.Multiple lines in the BOM have been matched to the same part. Please check if the matching is correct. ; | C41430893 | https://jlcpcb.com/partdetail/HanElectricity-CPG151101S1116/C41430893 | Extended | 122 | 122 JLCPCB | 4.4774
SW56 | LEFTALT | SW_Hotswap_Kailh_MX_1.25u |  | Select by Customer | CPG151101S11-16 | HanElectricity | SMD,14.5x5.9mm | 12V 2 3000gf 5,000 cycles SMD,14.5x5.9mm Mechanical Keyboard Shaft ROHS | Mechanical Keyboard Shaft | 1.Multiple lines in the BOM have been matched to the same part. Please check if the matching is correct. ; | C41430893 | https://jlcpcb.com/partdetail/HanElectricity-CPG151101S1116/C41430893 | Extended | 122 | 122 JLCPCB | 4.4774
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

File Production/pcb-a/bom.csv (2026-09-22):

Designator | Footprint | Quantity | Value | LCSC Part #
C1, C2, C3, C4, C5, C6 | 0805 | 6 | 100nF
D10, D11, D12, D13, D14, D15, D16, D17, D18, D19, D2, D20, D21, D22, D23, D24, D25, D26, D27, D28, D29, D3, D30, D31, D32, D33, D34, D35, D36, D37, D38, D39, D4, D40, D41, D42, D43, D44, D45, D46, D47, D48, D49, D5, D50, D51, D52, D53, D54, D55, D56, D57, D58, D59, D6, D60, D61, D62, D68, D69, D7, D8, D9 | LED_SK6812MINI-E_3.2x2.8mm_P1.5mm_ReverseMount | 63 | SK6812MINI-E
D103, D104, D105, D106, D111, D112, D113, D114, D115, D119, D120, D121, D122, D126, D127, D128, D129, D133, D134, D135, D136, D140, D141, D142, D143, D144, D147, D148, D149, D150, D151, D154, D155, D156, D158, D161, D162, D165, D63, D64, D65, D66, D67, D71, D72, D73, D74, D75, D79, D80, D81, D82, D83, D87, D88, D89, D90, D95, D96, D97, D98 | D_DO-35_SOD27_P7.62mm_Horizontal | 61 | 1N4148
J1 | USB_C_Receptacle_HCTL_HC-TYPE-C-16P-01A | 1 | USB_C_Receptacle_USB2.0_16P
R1, R2 | 0603 | 2 | 5.1k
R3 | 0603 | 1 | 10k
SW1 | SW_Hotswap_Kailh_MX_1.00u | 1 | ESC
SW10 | SW_Hotswap_Kailh_MX_1.00u | 1 | 9
SW11 | SW_Hotswap_Kailh_MX_1.00u | 1 | 0
SW12 | SW_Hotswap_Kailh_MX_1.00u | 1 | -
SW13 | SW_Hotswap_Kailh_MX_1.00u | 1 | =
SW14 | SW_Hotswap_Kailh_MX_2.00u | 1 | BACKSPACE
SW15 | SW_Hotswap_Kailh_MX_1.50u | 1 | TAB
SW16 | SW_Hotswap_Kailh_MX_1.00u | 1 | Q
SW17 | SW_Hotswap_Kailh_MX_1.00u | 1 | W
SW18 | SW_Hotswap_Kailh_MX_1.00u | 1 | E
SW19 | SW_Hotswap_Kailh_MX_1.00u | 1 | R
SW2 | SW_Hotswap_Kailh_MX_1.00u | 1 | 1
SW20 | SW_Hotswap_Kailh_MX_1.00u | 1 | T
SW21 | SW_Hotswap_Kailh_MX_1.00u | 1 | Y
SW22 | SW_Hotswap_Kailh_MX_1.00u | 1 | U
SW23 | SW_Hotswap_Kailh_MX_1.00u | 1 | I
SW24 | SW_Hotswap_Kailh_MX_1.00u | 1 | O
SW25 | SW_Hotswap_Kailh_MX_1.00u | 1 | P
SW26 | SW_Hotswap_Kailh_MX_1.00u | 1 | [
SW27 | SW_Hotswap_Kailh_MX_1.00u | 1 | ]
SW28 | SW_Hotswap_Kailh_MX_1.50u | 1 | \
SW29 | SW_Hotswap_Kailh_MX_1.75u | 1 | CAPSLOCK
SW3 | SW_Hotswap_Kailh_MX_1.00u | 1 | 2
SW30 | SW_Hotswap_Kailh_MX_1.00u | 1 | A
SW31 | SW_Hotswap_Kailh_MX_1.00u | 1 | S
SW32 | SW_Hotswap_Kailh_MX_1.00u | 1 | D
SW33 | SW_Hotswap_Kailh_MX_1.00u | 1 | F
SW34 | SW_Hotswap_Kailh_MX_1.00u | 1 | G
SW35 | SW_Hotswap_Kailh_MX_1.00u | 1 | H
SW36 | SW_Hotswap_Kailh_MX_1.00u | 1 | J
SW37 | SW_Hotswap_Kailh_MX_1.00u | 1 | K
SW38 | SW_Hotswap_Kailh_MX_1.00u | 1 | L
SW39 | SW_Hotswap_Kailh_MX_1.00u | 1 | ;
SW4 | SW_Hotswap_Kailh_MX_1.00u | 1 | 3
SW40 | SW_Hotswap_Kailh_MX_1.00u | 1 | '
SW41 | SW_Hotswap_Kailh_MX_2.25u | 1 | ENTER
SW42 | SW_Hotswap_Kailh_MX_2.25u | 1 | LEFTSHIFT
SW43 | SW_Hotswap_Kailh_MX_1.00u | 1 | Z
SW44 | SW_Hotswap_Kailh_MX_1.00u | 1 | X
SW45 | SW_Hotswap_Kailh_MX_1.00u | 1 | C
SW46 | SW_Hotswap_Kailh_MX_1.00u | 1 | V
SW47 | SW_Hotswap_Kailh_MX_1.00u | 1 | B
SW48 | SW_Hotswap_Kailh_MX_1.00u | 1 | N
SW49 | SW_Hotswap_Kailh_MX_1.00u | 1 | M
SW5 | SW_Hotswap_Kailh_MX_1.00u | 1 | 4
SW50 | SW_Hotswap_Kailh_MX_1.00u | 1 | ,
SW51 | SW_Hotswap_Kailh_MX_1.00u | 1 | .
SW52 | SW_Hotswap_Kailh_MX_1.00u | 1 | /
SW53 | SW_Hotswap_Kailh_MX_2.75u | 1 | RIGHTSHIFT
SW54 | SW_Hotswap_Kailh_MX_1.25u | 1 | LEFTCTRL
SW55 | SW_Hotswap_Kailh_MX_1.25u | 1 | LEFTWIN
SW56 | SW_Hotswap_Kailh_MX_1.25u | 1 | LEFTALT
SW57 | SW_Hotswap_Kailh_MX_6.25u | 1 | SPACE
SW58 | SW_Hotswap_Kailh_MX_1.25u | 1 | RIGHTALT
SW59 | SW_Hotswap_Kailh_MX_1.25u | 1 | FN
SW6 | SW_Hotswap_Kailh_MX_1.00u | 1 | 5
SW60 | SW_Hotswap_Kailh_MX_1.25u | 1 | MENU
SW61 | SW_Hotswap_Kailh_MX_1.25u | 1 | RIGHTCTRL
SW62 | SW_SPST_B3U-1000P | 1 | Boot
SW63 | SW_SPST_B3U-1000P | 1 | Reset
SW7 | SW_Hotswap_Kailh_MX_1.00u | 1 | 6
SW8 | SW_Hotswap_Kailh_MX_1.00u | 1 | 7
SW9 | SW_Hotswap_Kailh_MX_1.00u | 1 | 8
U1 | LQFP-48_7x7mm_P0.5mm | 1 | STM32F072C8Tx
U2 | ER_OLEDM0.91_1x-I2C | 1 | ER_OLEDM0.91_1x-I2C
U3 | SOT-223-3_TabPin2 | 1 | AMS1117-3.3
U4 | SOT-23-6 | 1 | USBLC6-2SC6

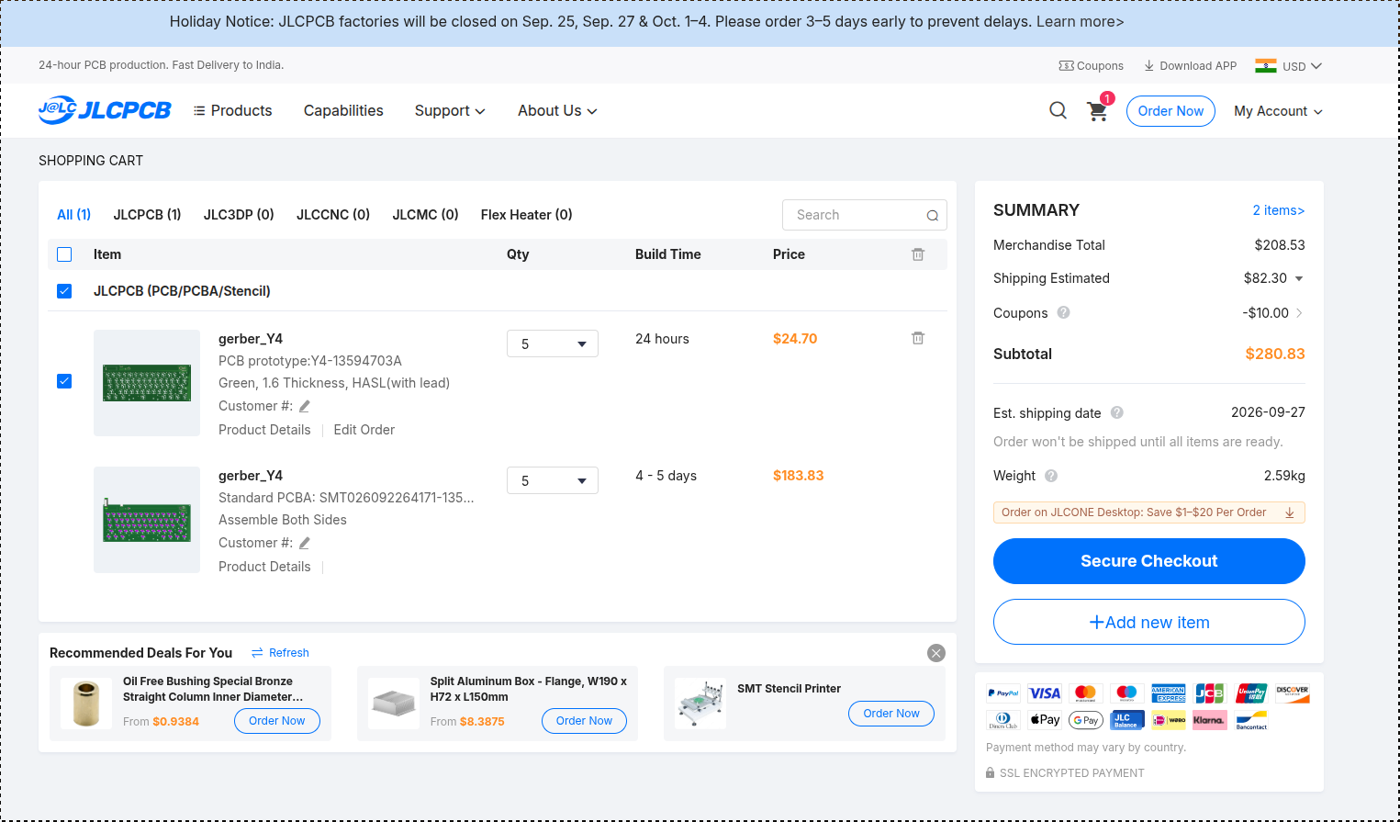
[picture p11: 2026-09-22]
images/bom.png

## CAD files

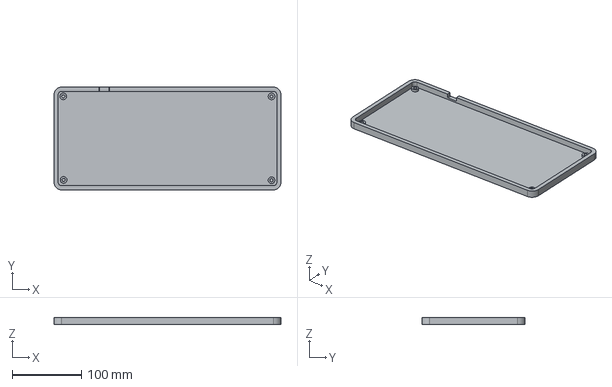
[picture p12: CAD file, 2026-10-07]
CAD/STEP/LowerSandwhich.step
327.6 x 148.3 x 10.0 mm

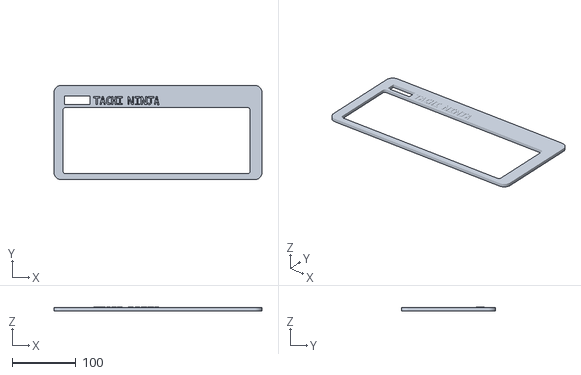
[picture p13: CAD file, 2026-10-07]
Production/cad-print/UpperSandwhich.stl
327.6 x 148.3 x 6.00

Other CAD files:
CAD/STEP/UpperSandwhich.step
Production/cad-print/LowerSandwhich.stl
CAD/LowerSandwhich.stl

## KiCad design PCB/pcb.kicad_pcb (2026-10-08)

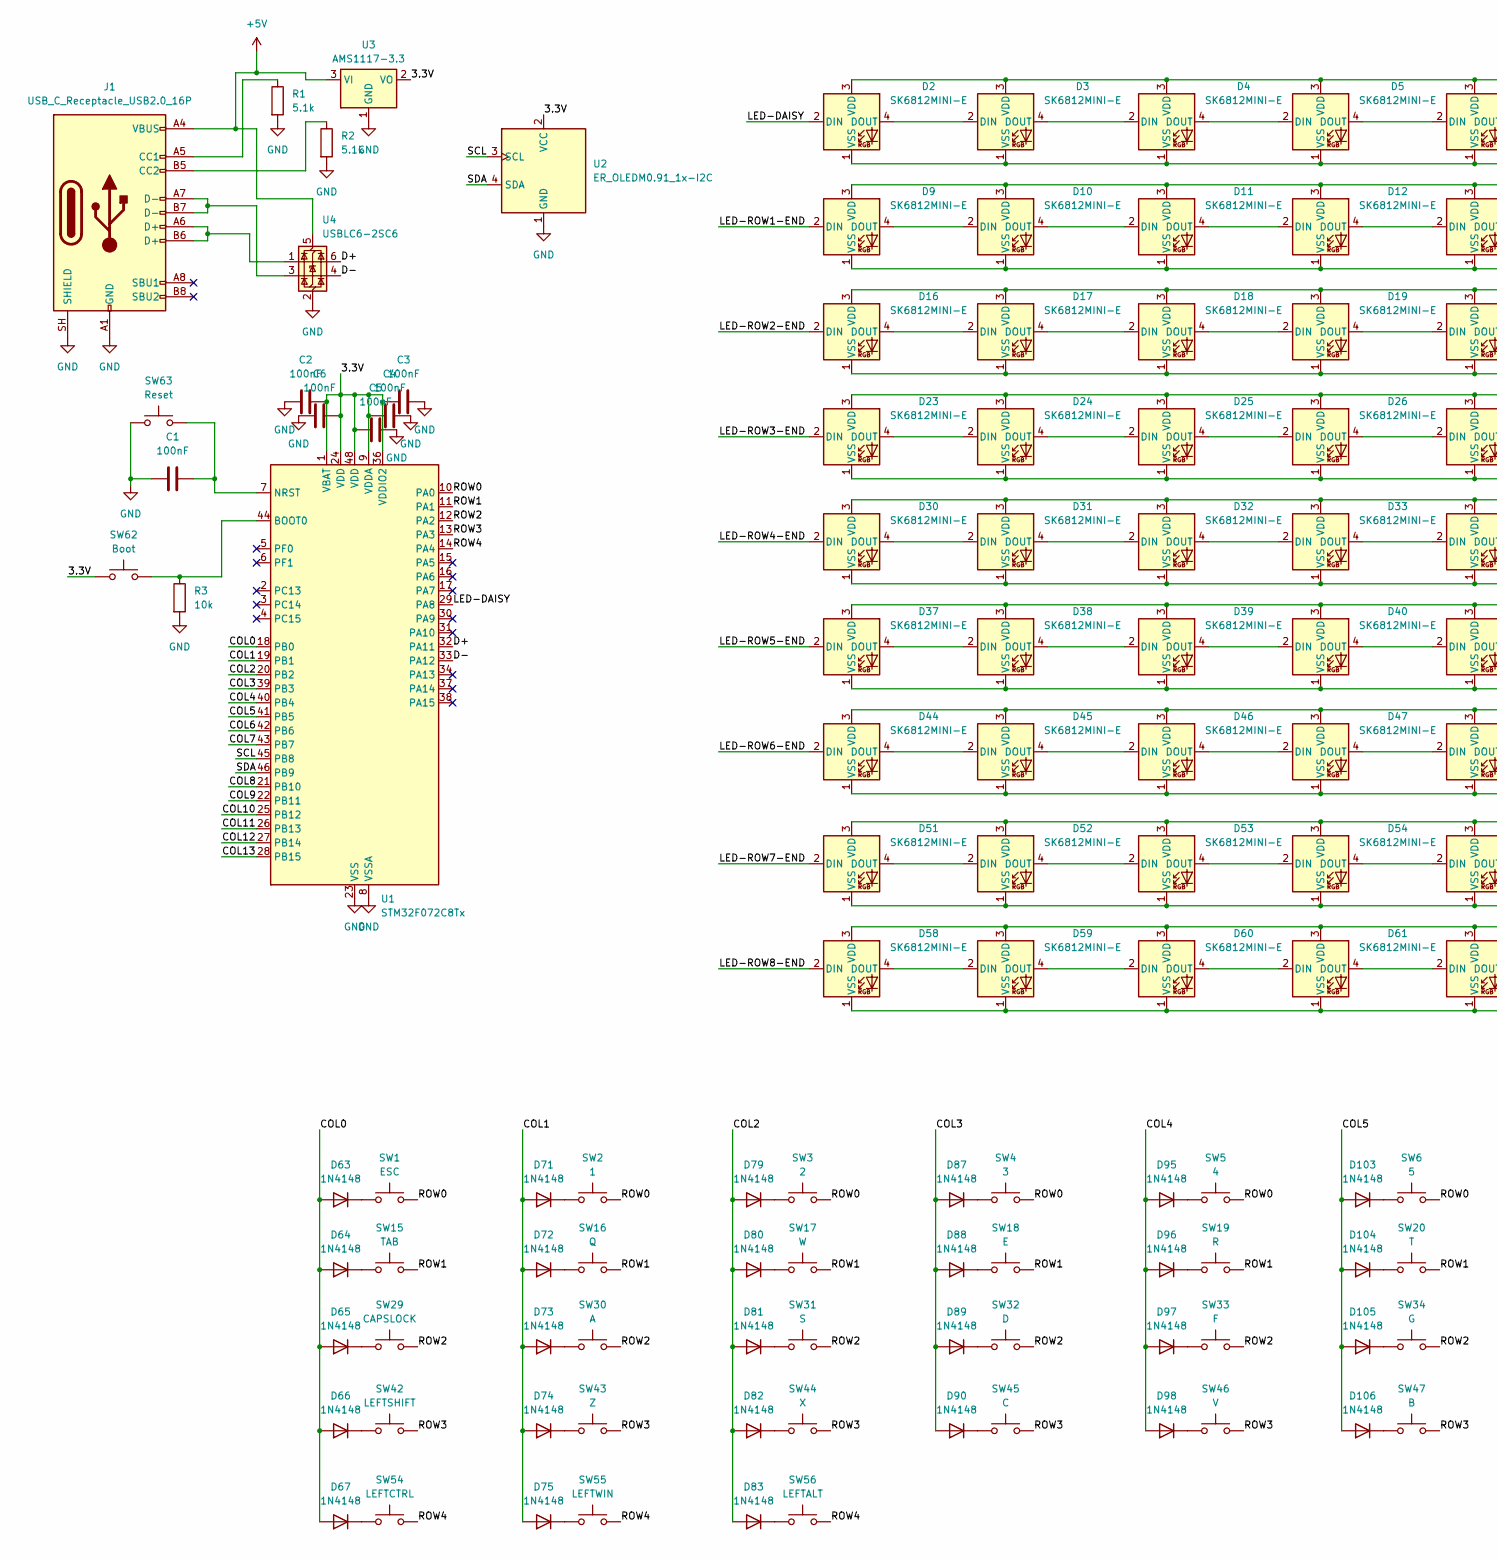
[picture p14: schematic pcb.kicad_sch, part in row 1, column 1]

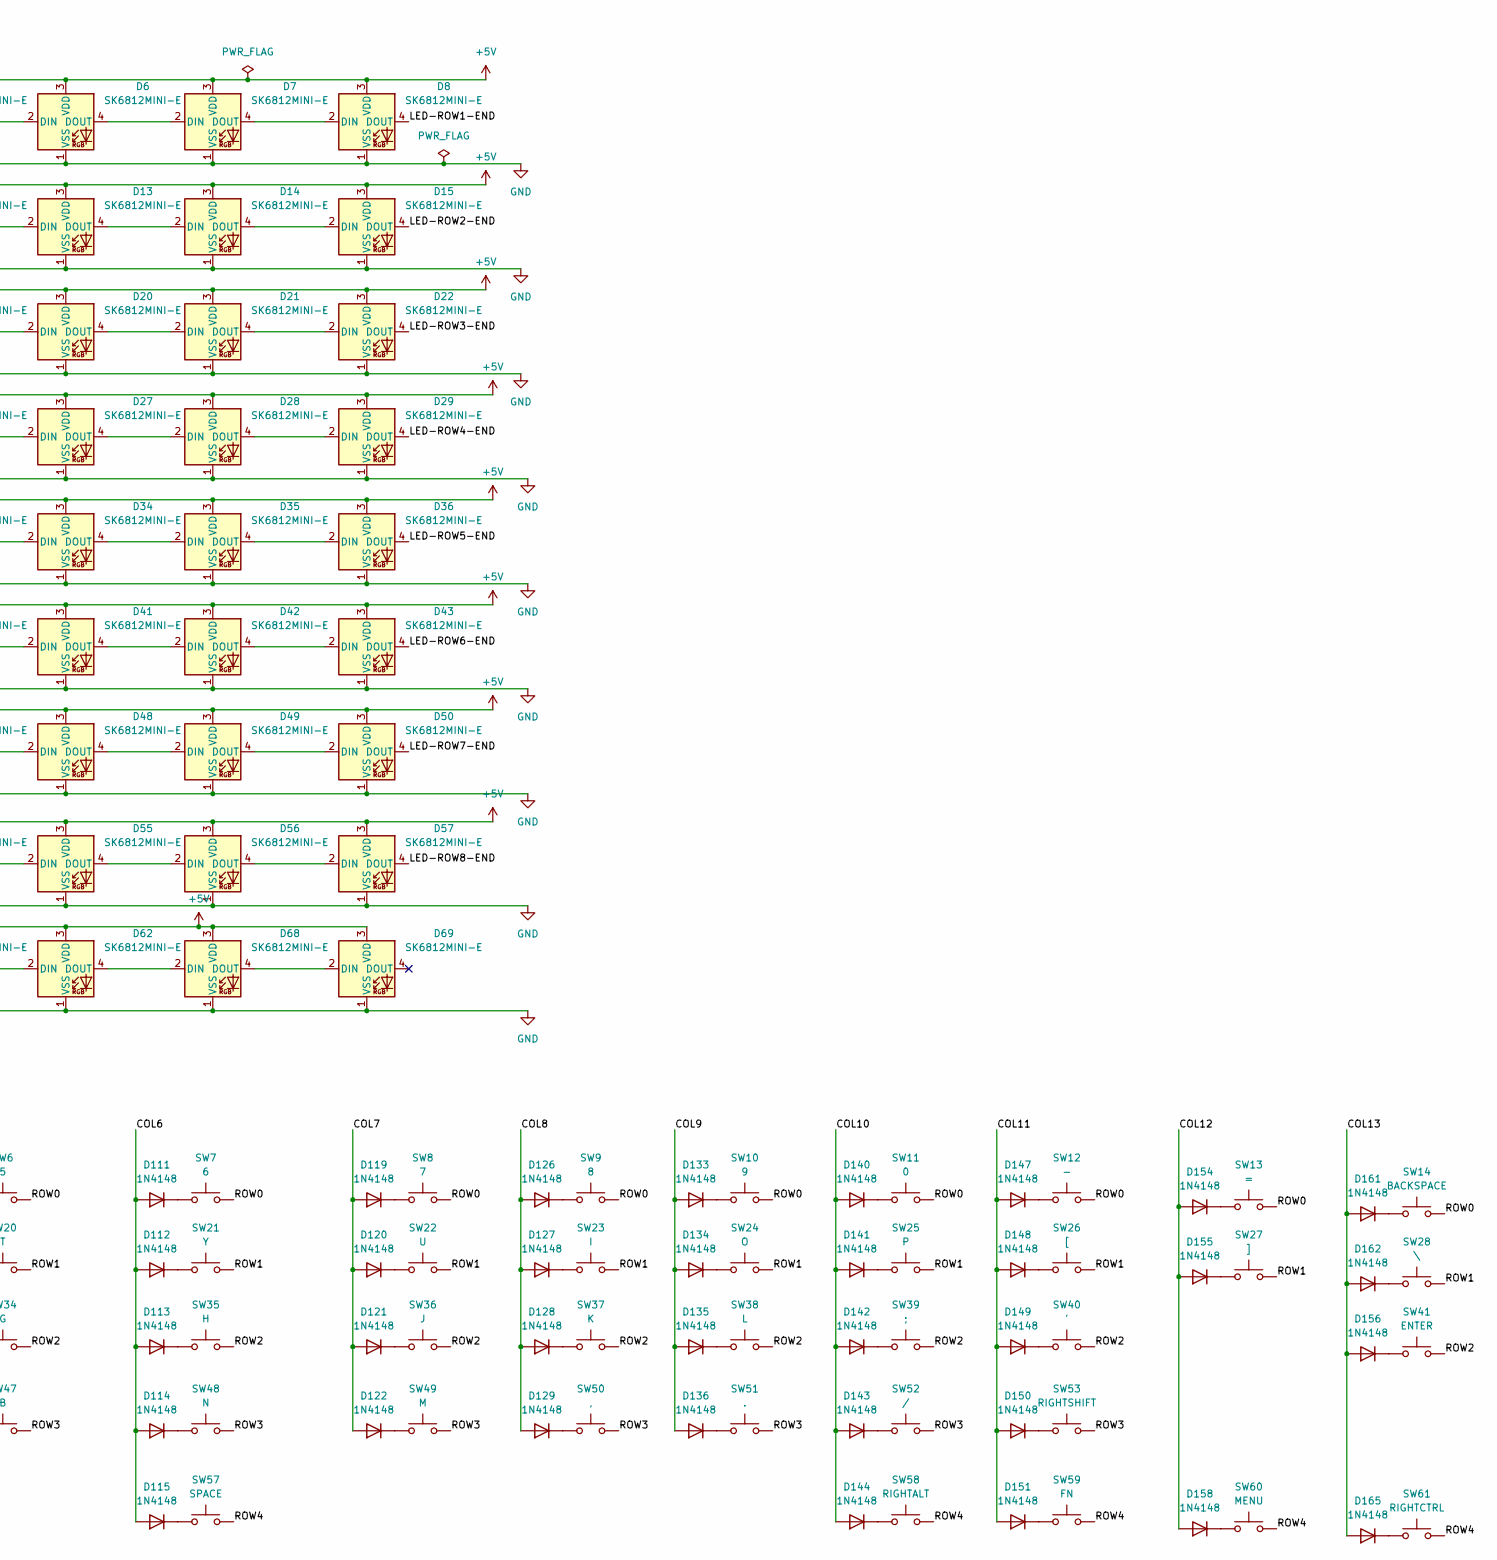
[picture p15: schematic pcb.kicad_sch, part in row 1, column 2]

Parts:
C1, C2, C3, C4, C5, C6: 100nF; C_0805_2012Metric
D2, D3, D4, D5, D6, D7, D8, D9, D10, D11, D12, D13, D14, D15, D16, D17, D18, D19, D20, D21, D22, D23, D24, D25, D26, D27, D28, D29, D30, D31, D32, D33, D34, D35, D36, D37, D38, D39, D40, D41, D42, D43, D44, D45, D46, D47, D48, D49, D50, D51, D52, D53, D54, D55, D56, D57, D58, D59, D60, D61, D62, D68, D69: SK6812MINI-E; LED_SK6812MINI-E_3.2x2.8mm_P1.5mm_ReverseMount
D63, D64, D65, D66, D67, D71, D72, D73, D74, D75, D79, D80, D81, D82, D83, D87, D88, D89, D90, D95, D96, D97, D98, D103, D104, D105, D106, D111, D112, D113, D114, D115, D119, D120, D121, D122, D126, D127, D128, D129, D133, D134, D135, D136, D140, D141, D142, D143, D144, D147, D148, D149, D150, D151, D154, D155, D156, D158, D161, D162, D165: 1N4148; D_DO-35_SOD27_P7.62mm_Horizontal
J1: USB_C_Receptacle_USB2.0_16P; USB_C_Receptacle_HCTL_HC-TYPE-C-16P-01A
R1, R2: 5.1k; R_0603_1608Metric
R3: 10k; R_0603_1608Metric
SW1: ESC; SW_Hotswap_Kailh_MX_1.00u
SW2: 1; SW_Hotswap_Kailh_MX_1.00u
SW3: 2; SW_Hotswap_Kailh_MX_1.00u
SW4: 3; SW_Hotswap_Kailh_MX_1.00u
SW5: 4; SW_Hotswap_Kailh_MX_1.00u
SW6: 5; SW_Hotswap_Kailh_MX_1.00u
SW7: 6; SW_Hotswap_Kailh_MX_1.00u
SW8: 7; SW_Hotswap_Kailh_MX_1.00u
SW9: 8; SW_Hotswap_Kailh_MX_1.00u
SW10: 9; SW_Hotswap_Kailh_MX_1.00u
SW11: 0; SW_Hotswap_Kailh_MX_1.00u
SW12: -; SW_Hotswap_Kailh_MX_1.00u
SW13: =; SW_Hotswap_Kailh_MX_1.00u
SW14: BACKSPACE; SW_Hotswap_Kailh_MX_2.00u
SW15: TAB; SW_Hotswap_Kailh_MX_1.50u
SW16: Q; SW_Hotswap_Kailh_MX_1.00u
SW17: W; SW_Hotswap_Kailh_MX_1.00u
SW18: E; SW_Hotswap_Kailh_MX_1.00u
SW19: R; SW_Hotswap_Kailh_MX_1.00u
SW20: T; SW_Hotswap_Kailh_MX_1.00u
SW21: Y; SW_Hotswap_Kailh_MX_1.00u
SW22: U; SW_Hotswap_Kailh_MX_1.00u
SW23: I; SW_Hotswap_Kailh_MX_1.00u
SW24: O; SW_Hotswap_Kailh_MX_1.00u
SW25: P; SW_Hotswap_Kailh_MX_1.00u
SW26: [; SW_Hotswap_Kailh_MX_1.00u
SW27: ]; SW_Hotswap_Kailh_MX_1.00u
SW28: \; SW_Hotswap_Kailh_MX_1.50u
SW29: CAPSLOCK; SW_Hotswap_Kailh_MX_1.75u
SW30: A; SW_Hotswap_Kailh_MX_1.00u
SW31: S; SW_Hotswap_Kailh_MX_1.00u
SW32: D; SW_Hotswap_Kailh_MX_1.00u
SW33: F; SW_Hotswap_Kailh_MX_1.00u
SW34: G; SW_Hotswap_Kailh_MX_1.00u
SW35: H; SW_Hotswap_Kailh_MX_1.00u
SW36: J; SW_Hotswap_Kailh_MX_1.00u
SW37: K; SW_Hotswap_Kailh_MX_1.00u
SW38: L; SW_Hotswap_Kailh_MX_1.00u
SW39: ;; SW_Hotswap_Kailh_MX_1.00u
SW40: '; SW_Hotswap_Kailh_MX_1.00u
SW41: ENTER; SW_Hotswap_Kailh_MX_2.25u
SW42: LEFTSHIFT; SW_Hotswap_Kailh_MX_2.25u
SW43: Z; SW_Hotswap_Kailh_MX_1.00u
SW44: X; SW_Hotswap_Kailh_MX_1.00u
SW45: C; SW_Hotswap_Kailh_MX_1.00u
SW46: V; SW_Hotswap_Kailh_MX_1.00u
SW47: B; SW_Hotswap_Kailh_MX_1.00u
SW48: N; SW_Hotswap_Kailh_MX_1.00u
SW49: M; SW_Hotswap_Kailh_MX_1.00u
SW50: ,; SW_Hotswap_Kailh_MX_1.00u
SW51: .; SW_Hotswap_Kailh_MX_1.00u
SW52: /; SW_Hotswap_Kailh_MX_1.00u
SW53: RIGHTSHIFT; SW_Hotswap_Kailh_MX_2.75u
SW54: LEFTCTRL; SW_Hotswap_Kailh_MX_1.25u
SW55: LEFTWIN; SW_Hotswap_Kailh_MX_1.25u
SW56: LEFTALT; SW_Hotswap_Kailh_MX_1.25u
SW57: SPACE; SW_Hotswap_Kailh_MX_6.25u
SW58: RIGHTALT; SW_Hotswap_Kailh_MX_1.25u
SW59: FN; SW_Hotswap_Kailh_MX_1.25u
SW60: MENU; SW_Hotswap_Kailh_MX_1.25u
SW61: RIGHTCTRL; SW_Hotswap_Kailh_MX_1.25u
SW62: Boot; SW_SPST_B3U-1000P
SW63: Reset; SW_SPST_B3U-1000P
U1: STM32F072C8Tx; LQFP-48_7x7mm_P0.5mm
U2: ER_OLEDM0.91_1x-I2C
U3: AMS1117-3.3; SOT-223-3_TabPin2
U4: USBLC6-2SC6; SOT-23-6

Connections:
+5V: D2.3 (VDD), D3.3 (VDD), D4.3 (VDD), D5.3 (VDD), D6.3 (VDD), D7.3 (VDD), D8.3 (VDD), D9.3 (VDD), D10.3 (VDD), D11.3 (VDD), D12.3 (VDD), D13.3 (VDD), D14.3 (VDD), D15.3 (VDD), D16.3 (VDD), D17.3 (VDD), D18.3 (VDD), D19.3 (VDD), D20.3 (VDD), D21.3 (VDD), D22.3 (VDD), D23.3 (VDD), D24.3 (VDD), D25.3 (VDD), D26.3 (VDD), D27.3 (VDD), D28.3 (VDD), D29.3 (VDD), D30.3 (VDD), D31.3 (VDD), D32.3 (VDD), D33.3 (VDD), D34.3 (VDD), D35.3 (VDD), D36.3 (VDD), D37.3 (VDD), D38.3 (VDD), D39.3 (VDD), D40.3 (VDD), D41.3 (VDD), D42.3 (VDD), D43.3 (VDD), D44.3 (VDD), D45.3 (VDD), D46.3 (VDD), D47.3 (VDD), D48.3 (VDD), D49.3 (VDD), D50.3 (VDD), D51.3 (VDD), D52.3 (VDD), D53.3 (VDD), D54.3 (VDD), D55.3 (VDD), D56.3 (VDD), D57.3 (VDD), D58.3 (VDD), D59.3 (VDD), D60.3 (VDD), D61.3 (VDD), D62.3 (VDD), D68.3 (VDD), D69.3 (VDD), J1.A4 (VBUS), J1.A9 (VBUS), J1.B4 (VBUS), J1.B9 (VBUS), U3.3 (VI), U4.5 (VBUS)
/3.3V: C2.1, C3.2, C4.2, C5.2, C6.1, SW62.1, U1.1 (VBAT), U1.9 (VDDA), U1.24 (VDD), U1.36 (VDDIO2), U1.48 (VDD), U2.2 (VCC), U3.2 (VO)
/COL0: D63.2 (A), D64.2 (A), D65.2 (A), D66.2 (A), D67.2 (A), U1.18 (PB0)
/COL1: D71.2 (A), D72.2 (A), D73.2 (A), D74.2 (A), D75.2 (A), U1.19 (PB1)
/COL2: D79.2 (A), D80.2 (A), D81.2 (A), D82.2 (A), D83.2 (A), U1.20 (PB2)
/COL3: D87.2 (A), D88.2 (A), D89.2 (A), D90.2 (A), U1.39 (PB3)
/COL4: D95.2 (A), D96.2 (A), D97.2 (A), D98.2 (A), U1.40 (PB4)
/COL5: D103.2 (A), D104.2 (A), D105.2 (A), D106.2 (A), U1.41 (PB5)
/COL6: D111.2 (A), D112.2 (A), D113.2 (A), D114.2 (A), D115.2 (A), U1.42 (PB6)
/COL7: D119.2 (A), D120.2 (A), D121.2 (A), D122.2 (A), U1.43 (PB7)
/COL8: D126.2 (A), D127.2 (A), D128.2 (A), D129.2 (A), U1.21 (PB10)
/COL9: D133.2 (A), D134.2 (A), D135.2 (A), D136.2 (A), U1.22 (PB11)
/COL10: D140.2 (A), D141.2 (A), D142.2 (A), D143.2 (A), D144.2 (A), U1.25 (PB12)
/COL11: D147.2 (A), D148.2 (A), D149.2 (A), D150.2 (A), D151.2 (A), U1.26 (PB13)
/COL12: D154.2 (A), D155.2 (A), D158.2 (A), U1.27 (PB14)
/COL13: D156.2 (A), D161.2 (A), D162.2 (A), D165.2 (A), U1.28 (PB15)
/D+: U1.32 (PA11), U4.6 (I/O1)
/D-: U1.33 (PA12), U4.4 (I/O2)
/LED-DAISY: D2.2 (DIN), U1.29 (PA8)
/LED-ROW1-END: D8.4 (DOUT), D9.2 (DIN)
/LED-ROW2-END: D15.4 (DOUT), D16.2 (DIN)
/LED-ROW3-END: D22.4 (DOUT), D23.2 (DIN)
/LED-ROW4-END: D29.4 (DOUT), D30.2 (DIN)
/LED-ROW5-END: D36.4 (DOUT), D37.2 (DIN)
/LED-ROW6-END: D43.4 (DOUT), D44.2 (DIN)
/LED-ROW7-END: D50.4 (DOUT), D51.2 (DIN)
/LED-ROW8-END: D57.4 (DOUT), D58.2 (DIN)
/ROW0: SW1.2, SW2.2, SW3.2, SW4.2, SW5.2, SW6.2, SW7.2, SW8.2, SW9.2, SW10.2, SW11.2, SW12.2, SW13.2, SW14.2, U1.10 (PA0)
/ROW1: SW15.2, SW16.2, SW17.2, SW18.2, SW19.2, SW20.2, SW21.2, SW22.2, SW23.2, SW24.2, SW25.2, SW26.2, SW27.2, SW28.2, U1.11 (PA1)
/ROW2: SW29.2, SW30.2, SW31.2, SW32.2, SW33.2, SW34.2, SW35.2, SW36.2, SW37.2, SW38.2, SW39.2, SW40.2, SW41.2, U1.12 (PA2)
/ROW3: SW42.2, SW43.2, SW44.2, SW45.2, SW46.2, SW47.2, SW48.2, SW49.2, SW50.2, SW51.2, SW52.2, SW53.2, U1.13 (PA3)
/ROW4: SW54.2, SW55.2, SW56.2, SW57.2, SW58.2, SW59.2, SW60.2, SW61.2, U1.14 (PA4)
/SCL: U1.45 (PB8), U2.3 (SCL)
/SDA: U1.46 (PB9), U2.4 (SDA)
GND: C1.1, C2.2, C3.1, C4.1, C5.1, C6.2, D2.1 (VSS), D3.1 (VSS), D4.1 (VSS), D5.1 (VSS), D6.1 (VSS), D7.1 (VSS), D8.1 (VSS), D9.1 (VSS), D10.1 (VSS), D11.1 (VSS), D12.1 (VSS), D13.1 (VSS), D14.1 (VSS), D15.1 (VSS), D16.1 (VSS), D17.1 (VSS), D18.1 (VSS), D19.1 (VSS), D20.1 (VSS), D21.1 (VSS), D22.1 (VSS), D23.1 (VSS), D24.1 (VSS), D25.1 (VSS), D26.1 (VSS), D27.1 (VSS), D28.1 (VSS), D29.1 (VSS), D30.1 (VSS), D31.1 (VSS), D32.1 (VSS), D33.1 (VSS), D34.1 (VSS), D35.1 (VSS), D36.1 (VSS), D37.1 (VSS), D38.1 (VSS), D39.1 (VSS), D40.1 (VSS), D41.1 (VSS), D42.1 (VSS), D43.1 (VSS), D44.1 (VSS), D45.1 (VSS), D46.1 (VSS), D47.1 (VSS), D48.1 (VSS), D49.1 (VSS), D50.1 (VSS), D51.1 (VSS), D52.1 (VSS), D53.1 (VSS), D54.1 (VSS), D55.1 (VSS), D56.1 (VSS), D57.1 (VSS), D58.1 (VSS), D59.1 (VSS), D60.1 (VSS), D61.1 (VSS), D62.1 (VSS), D68.1 (VSS), D69.1 (VSS), J1.A1 (GND), J1.A12 (GND), J1.B1 (GND), J1.B12 (GND), J1.SH (SHIELD), R1.2, R2.2, R3.2, SW63.1, U1.8 (VSSA), U1.23 (VSS), U1.35 (VSS), U1.47 (VSS), U2.1 (GND), U3.1 (GND), U4.2 (GND)
unnamed: D2.4 (DOUT), D3.2 (DIN)
unnamed: D3.4 (DOUT), D4.2 (DIN)
unnamed: D4.4 (DOUT), D5.2 (DIN)
unnamed: D5.4 (DOUT), D6.2 (DIN)
unnamed: D6.4 (DOUT), D7.2 (DIN)
unnamed: D7.4 (DOUT), D8.2 (DIN)
unnamed: D9.4 (DOUT), D10.2 (DIN)
unnamed: D10.4 (DOUT), D11.2 (DIN)
unnamed: D11.4 (DOUT), D12.2 (DIN)
unnamed: D12.4 (DOUT), D13.2 (DIN)
unnamed: D13.4 (DOUT), D14.2 (DIN)
unnamed: D14.4 (DOUT), D15.2 (DIN)
unnamed: D16.4 (DOUT), D17.2 (DIN)
unnamed: D17.4 (DOUT), D18.2 (DIN)
unnamed: D18.4 (DOUT), D19.2 (DIN)
unnamed: D19.4 (DOUT), D20.2 (DIN)
unnamed: D20.4 (DOUT), D21.2 (DIN)
unnamed: D21.4 (DOUT), D22.2 (DIN)
unnamed: D23.4 (DOUT), D24.2 (DIN)
unnamed: D24.4 (DOUT), D25.2 (DIN)
unnamed: D25.4 (DOUT), D26.2 (DIN)
unnamed: D26.4 (DOUT), D27.2 (DIN)
unnamed: D27.4 (DOUT), D28.2 (DIN)
unnamed: D28.4 (DOUT), D29.2 (DIN)
unnamed: D30.4 (DOUT), D31.2 (DIN)
unnamed: D31.4 (DOUT), D32.2 (DIN)
unnamed: D32.4 (DOUT), D33.2 (DIN)
unnamed: D33.4 (DOUT), D34.2 (DIN)
unnamed: D34.4 (DOUT), D35.2 (DIN)
unnamed: D35.4 (DOUT), D36.2 (DIN)
unnamed: D37.4 (DOUT), D38.2 (DIN)
unnamed: D38.4 (DOUT), D39.2 (DIN)
unnamed: D39.4 (DOUT), D40.2 (DIN)
unnamed: D40.4 (DOUT), D41.2 (DIN)
unnamed: D41.4 (DOUT), D42.2 (DIN)
unnamed: D42.4 (DOUT), D43.2 (DIN)
unnamed: D44.4 (DOUT), D45.2 (DIN)
unnamed: D45.4 (DOUT), D46.2 (DIN)
unnamed: D46.4 (DOUT), D47.2 (DIN)
unnamed: D47.4 (DOUT), D48.2 (DIN)
unnamed: D48.4 (DOUT), D49.2 (DIN)
unnamed: D49.4 (DOUT), D50.2 (DIN)
unnamed: D51.4 (DOUT), D52.2 (DIN)
unnamed: D52.4 (DOUT), D53.2 (DIN)
unnamed: D53.4 (DOUT), D54.2 (DIN)
unnamed: D54.4 (DOUT), D55.2 (DIN)
unnamed: D55.4 (DOUT), D56.2 (DIN)
unnamed: D56.4 (DOUT), D57.2 (DIN)
unnamed: D58.4 (DOUT), D59.2 (DIN)
unnamed: D59.4 (DOUT), D60.2 (DIN)
unnamed: D60.4 (DOUT), D61.2 (DIN)
unnamed: D61.4 (DOUT), D62.2 (DIN)
unnamed: D62.4 (DOUT), D68.2 (DIN)
unnamed: D63.1 (K), SW1.1
unnamed: D64.1 (K), SW15.1
unnamed: D65.1 (K), SW29.1
unnamed: D66.1 (K), SW42.1
unnamed: D67.1 (K), SW54.1
unnamed: D68.4 (DOUT), D69.2 (DIN)
unnamed: D71.1 (K), SW2.1
unnamed: D72.1 (K), SW16.1
unnamed: D73.1 (K), SW30.1
unnamed: D74.1 (K), SW43.1
unnamed: D75.1 (K), SW55.1
unnamed: D79.1 (K), SW3.1
unnamed: D80.1 (K), SW17.1
unnamed: D81.1 (K), SW31.1
unnamed: D82.1 (K), SW44.1
unnamed: D83.1 (K), SW56.1
unnamed: D87.1 (K), SW4.1
unnamed: D88.1 (K), SW18.1
unnamed: D89.1 (K), SW32.1
unnamed: D90.1 (K), SW45.1
unnamed: D95.1 (K), SW5.1
unnamed: D96.1 (K), SW19.1
unnamed: D97.1 (K), SW33.1
unnamed: D98.1 (K), SW46.1
unnamed: D103.1 (K), SW6.1
unnamed: D104.1 (K), SW20.1
unnamed: D105.1 (K), SW34.1
unnamed: D106.1 (K), SW47.1
unnamed: D111.1 (K), SW7.1
unnamed: D112.1 (K), SW21.1
unnamed: D113.1 (K), SW35.1
unnamed: D114.1 (K), SW48.1
unnamed: D115.1 (K), SW57.1
unnamed: D119.1 (K), SW8.1
unnamed: D120.1 (K), SW22.1
unnamed: D121.1 (K), SW36.1
unnamed: D122.1 (K), SW49.1
unnamed: D126.1 (K), SW9.1
unnamed: D127.1 (K), SW23.1
unnamed: D128.1 (K), SW37.1
unnamed: D129.1 (K), SW50.1
unnamed: D133.1 (K), SW10.1
unnamed: D134.1 (K), SW24.1
unnamed: D135.1 (K), SW38.1
unnamed: D136.1 (K), SW51.1
unnamed: D140.1 (K), SW11.1
unnamed: D141.1 (K), SW25.1
unnamed: D142.1 (K), SW39.1
unnamed: D143.1 (K), SW52.1
unnamed: D144.1 (K), SW58.1
unnamed: D147.1 (K), SW12.1
unnamed: D148.1 (K), SW26.1
unnamed: D149.1 (K), SW40.1
unnamed: D150.1 (K), SW53.1
unnamed: D151.1 (K), SW59.1
unnamed: D154.1 (K), SW13.1
unnamed: D155.1 (K), SW27.1
unnamed: D156.1 (K), SW41.1
unnamed: D158.1 (K), SW60.1
unnamed: D161.1 (K), SW14.1
unnamed: D162.1 (K), SW28.1
unnamed: D165.1 (K), SW61.1
unnamed: J1.A5 (CC1), R1.1
unnamed: J1.B5 (CC2), R2.1
unnamed: J1.A6 (D+), J1.B6 (D+), U4.1 (I/O1)
unnamed: J1.A7 (D-), J1.B7 (D-), U4.3 (I/O2)
unnamed: R3.1, SW62.2, U1.44 (BOOT0)
unnamed: C1.2, SW63.2, U1.7 (NRST)

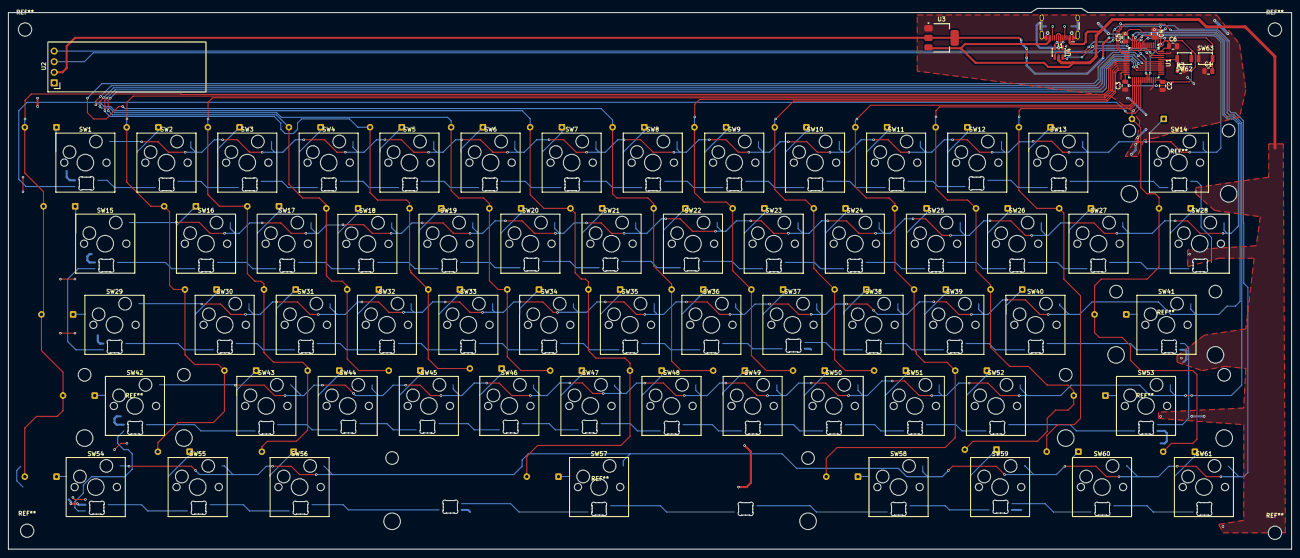
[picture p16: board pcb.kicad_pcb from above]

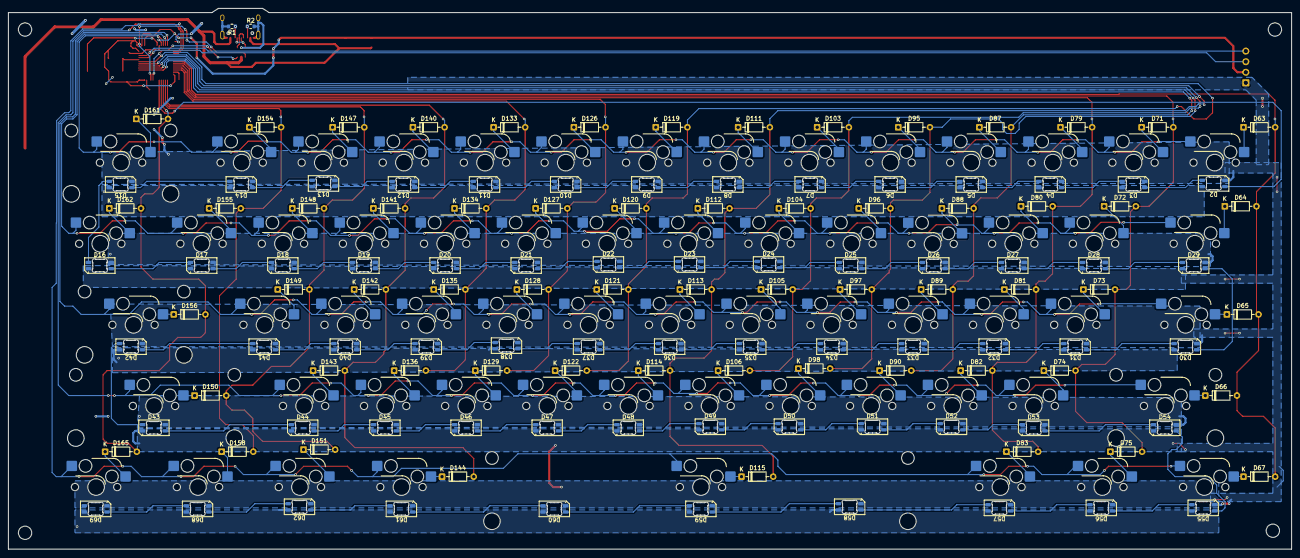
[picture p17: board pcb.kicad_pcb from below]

Board: 2 copper layers, 308.5 x 130.0 mm, 201 parts (126 on the bottom side), 156 nets.

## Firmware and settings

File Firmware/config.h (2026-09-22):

#pragma once

/* ===== Matrix (verified against pcb.kicad_sch net labels) ===== */
#define MATRIX_ROW_PINS { A0, A1, A2, A3, A4 }
#define MATRIX_COL_PINS { B0, B1, B2, B3, B4, B5, B6, B7, B10, B11, B12, B13, B14, B15 }
#define DIODE_DIRECTION COL2ROW  // confirmed: D64 anode->COL0, cathode->switch->ROW1
#define DEBOUNCE 5

/* ===== RGB Matrix (WS2812 daisy chain, 64 LEDs) ===== */
#define RGB_MATRIX_LED_COUNT 64
#define RGB_DI_PIN A8           // confirmed: net "LED-DAISY" on PA8
#define WS2812_PWM_DRIVER PWMD1 // TODO: verify timer/channel — PA8 is TIM1_CH1 on F072, confirm in ChibiOS mcuconf.h
#define WS2812_PWM_CHANNEL 1
#define WS2812_DMA_STREAM STM32_DMA1_STREAM2
#define WS2812_DMA_CHANNEL 5

#define RGB_MATRIX_KEYPRESSES
#define RGB_MATRIX_DEFAULT_MODE RGB_MATRIX_CYCLE_LEFT_RIGHT
#define RGB_MATRIX_DEFAULT_HUE 0
#define RGB_MATRIX_DEFAULT_SAT 255
#define RGB_MATRIX_DEFAULT_VAL 120   // capped below max to keep current draw reasonable — raise carefully
#define RGB_MATRIX_DEFAULT_SPD 128
#define RGB_MATRIX_MAXIMUM_BRIGHTNESS 180 // safety cap given 64 LEDs on shared 5V rail

/* ===== I2C (OLED, if you enable OLED_ENABLE in rules.mk) ===== */
// Confirmed from schematic: SCL = PB8, SDA = PB9
#define I2C1_SCL_PIN B8
#define I2C1_SDA_PIN B9
#define I2C1_SCL_PAL_MODE 1   // TODO: verify AF mode number for I2C1 on F072 in ChibiOS docs
#define I2C1_SDA_PAL_MODE 1

/* ===== USB ===== */
#define USB_MAX_POWER_CONSUMPTION 500

/* ===== Debounce / NKRO ===== */
#define FORCE_NKRO

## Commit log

2026-09-20 Add BOM and production gerber files
    [pcb-B_Cu.gbr, pcb-B_Mask.gbr, pcb-B_Paste.gbr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]
2026-09-20 Update README with BOM and pricing details
    Added BOM section with pricing information and notes.
2026-09-20 Added more stuffs
    [pcb-B_Cu.gbr, pcb-B_Mask.gbr, pcb-B_Paste.gbr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]
2026-09-21 Add shipping cost to BOM in README
    Updated BOM table to include shipping cost information.
2026-09-21 Revise BOM pricing and include images
    Updated pricing information and added images section.
2026-09-21 Revise BOM total and add stabilizers
    Updated total cost in BOM section and added stabilizers entry.
2026-09-21 Revise BOM with new links and updated total cost
    Updated stabilizer link and added solder item to BOM. Adjusted total cost.
2026-09-21 Add CAD sandwich models and updated production files
    [LowerSandwhich.step, LowerSandwhich.stl, UpperSandwhich.step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]
2026-09-22 Introducing... Tachi Ninja V2
    [LowerSandwhich.step, LowerSandwhich.stl, UpperSandwhich.step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]
2026-09-22 Preparing BOM
    [BOM-withLCSC.xls, bom.csv, positions.csv]
2026-09-22 Fix image syntax in BOM.md
2026-09-22 Update README with BOM recommendation
    Added a recommendation for a BOM document for more details.
2026-09-23 Update BOM with cost details and item links
    Added a detailed breakdown of costs for components including links and prices.
2026-09-23 Update BOM with total costs and customs information
    Added a summary of total costs including JLCPCB Assembly and customs fees.
2026-09-23 Revise Bill of Materials with new entries and costs
    Updated BOM with new images, cost details, and additional items.
2026-09-23 Enhance BOM with LCSC details and final budget summary
    Added LCSC components table and updated budget summary with customs information.
2026-09-23 Revise BOM with detailed items and links
    Updated the BOM section with detailed itemized list and links.
2026-09-23 Final push before ship
    [bom.csv, pcb.kicad_pcb, positions.csv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]
2026-09-25 Update README with assembly instructions
    Added instructions for obtaining and assembling the keyboard.
2026-10-07 Changed V2 model wih V3 model
    [LowerSandwhich.step, LowerSandwhich.stl, UpperSandwhich.step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]
2026-10-08 change V2 pcb to V3
    [positions.csv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]
2026-10-08 change the pcb-kicad from V2 to V3
    [pcb.kicad_pcb]
2026-10-08 fixed outaded pcb interpreted as V3
